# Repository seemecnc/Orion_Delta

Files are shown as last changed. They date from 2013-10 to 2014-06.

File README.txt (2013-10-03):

The ORION Delta 3D Printer by SeeMeCNC

Open-Source Files are published here on github, free to use/modify/share as you like.  We hope that some part of this design will inspire you to build and create new things!  If it does, please share your ideas/designs/concepts either through github here, or on 
http://forum.seemecnc.com  

Firmware used is a fork of repeater-firmware, and is kept in this github repo and maintained to be a direct drop-in for all pre-assembled ORION machines.  

The ORION Delta 3D Printer is a new delta-platform machine developed by SeeMeCNC.  Designed to be more compact than the Rostock MAX, more portable and more rigid. 

The ORION is a derivative stemming from our original Rostock MAX, which is a derivative of Johann's Rostock "original".  While there are many new delta designs, the ORION is built on solid, proven history, including many changes and design enhancements from both the community, as well as observations from running multiple delta machines for thousands of hours.  

All plastic parts are injection molded, with the exception of the EZ Fan shroud, which is printed on the machine as a first test-print, then attached to the next machine being assembled :)  All CNC machined parts are made from either Aluminum, Brass or PEEK (the hot end insulator).  Lasercut parts are produced from 1/4" Melamine laminated, which is comprised of an MDF core with high temp, high pressure melamine laminate on both surfaces.  This provides a light weight, yet rigid framework that is far more stable than a plywood material to moisture, pressure, temperature etc…

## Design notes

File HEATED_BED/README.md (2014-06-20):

ORION Heated Bed files

Designed by partdaddy

Released as open-source hardware with attribution

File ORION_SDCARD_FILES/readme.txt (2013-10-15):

The files on the SD card are included on the machine once shipped.

There is a folder for FIRMWARE which contains the actual firmware used on 
your machine.  

The folder labeled GCODE has sample gcode prints that were printed on your machine
to test it before shipping

The folder calibration contains GCODE files that can be used to calibrate
the three towers

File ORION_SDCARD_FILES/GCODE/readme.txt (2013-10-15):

fan.gco is the printable fan shroud for the 25mm fan on the platform.
It isn't necessary, but is a printable add-on, something fun to print
on your machine!

blinky.gco is the Blinky Eye token we print and send with your machine.  You can
download the original from http://repables.com

vase.gco is another sample print we use on your machine.  It is from thingiverse.com, 
and can be downloaded from the link http://www.thingiverse.com/thing:18672

ENJOY!

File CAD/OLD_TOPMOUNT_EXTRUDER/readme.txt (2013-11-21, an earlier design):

These are the CAD files for the original top mounted extruder setup like was shown on the 
prototype machine released at Detroit maker faire.  These files will only work with the first design top plate with the cutouts, or you 
could drill your own mounting holes

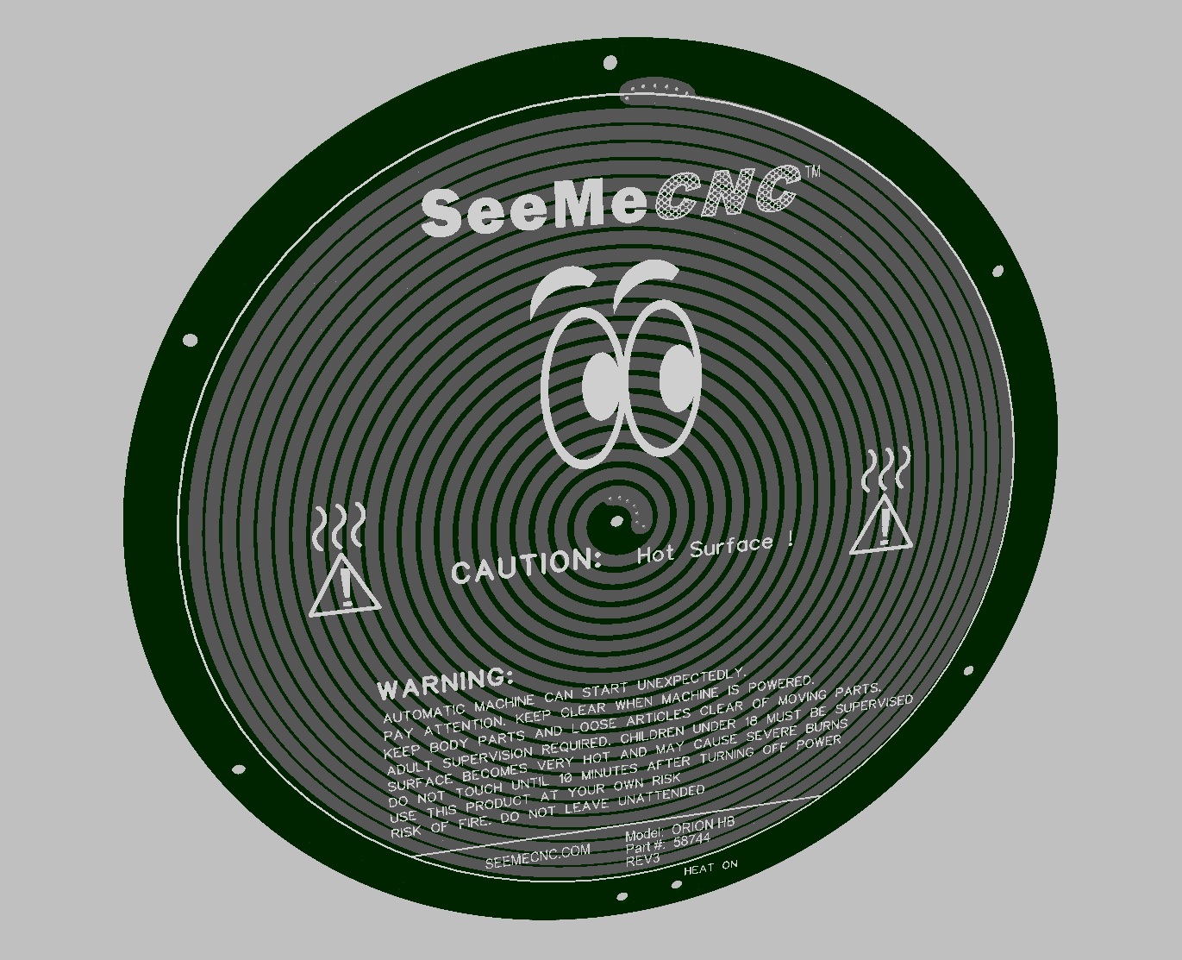
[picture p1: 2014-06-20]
HEATED_BED/58744 ORION HB REV3/58744 ORION HB REV3.jpg

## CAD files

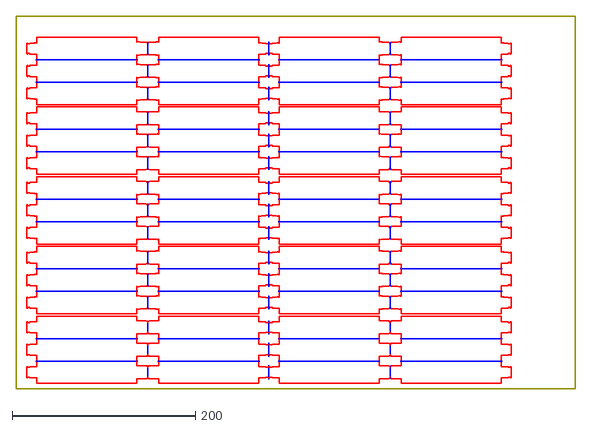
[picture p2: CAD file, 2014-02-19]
CAD/ACRYLIC_IDLER_COVERS.DXF
609.6 x 406.4

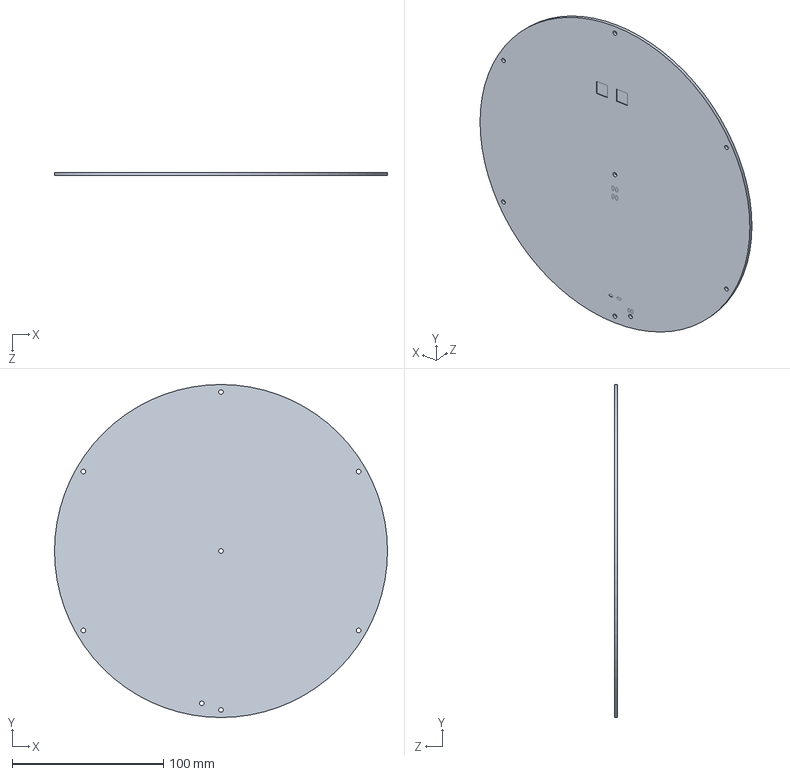
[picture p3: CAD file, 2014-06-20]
HEATED_BED/ORION HEATED BED.SLDPRT
220.0 x 220.0 x 2.20 mm

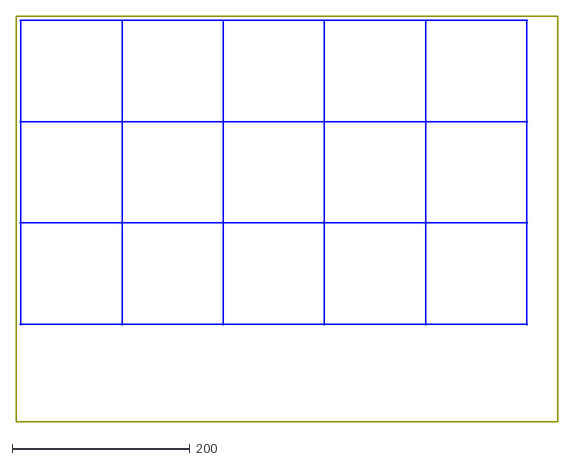
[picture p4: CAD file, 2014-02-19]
CAD/ACRYLIC_SQUARES_114MM.DXF
609.6 x 457.2

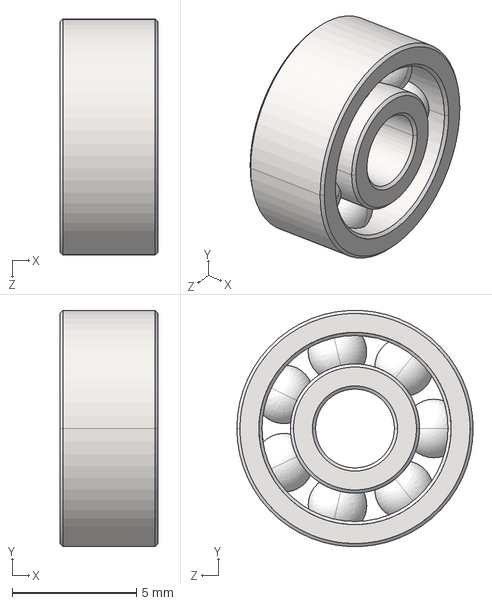
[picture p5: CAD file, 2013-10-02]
CAD/IGES/Ball Bearing 0125ID - 0375OD - 0156W.IGS
3.96 x 9.51 x 9.53 mm

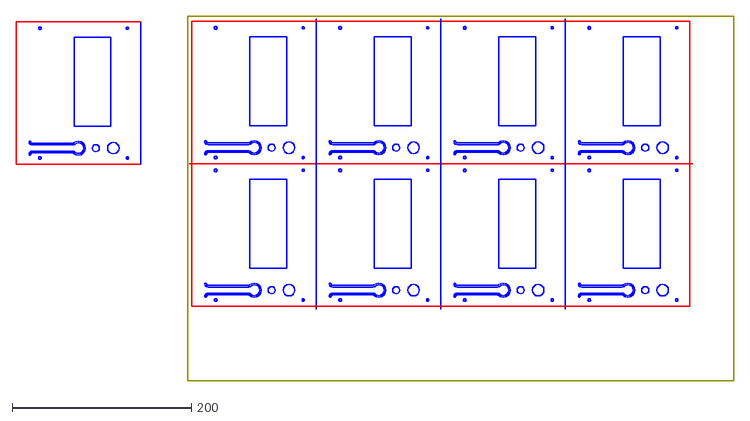
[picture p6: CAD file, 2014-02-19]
CAD/ACRYLIC_FACEPLATE_FLEXY_V3.DXF
801.1 x 406.4

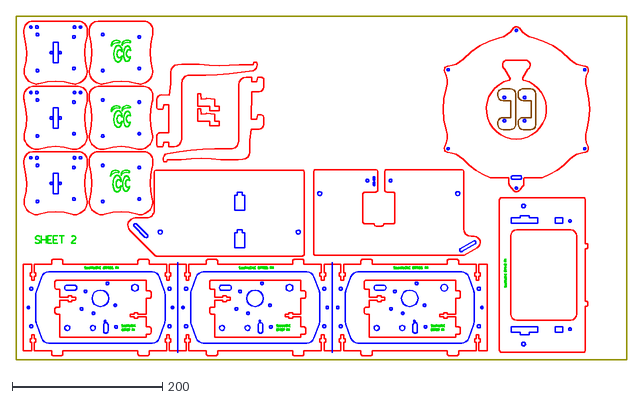
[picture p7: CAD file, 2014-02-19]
CAD/ORION_SHEET_2.DXF
812.8 x 457.2

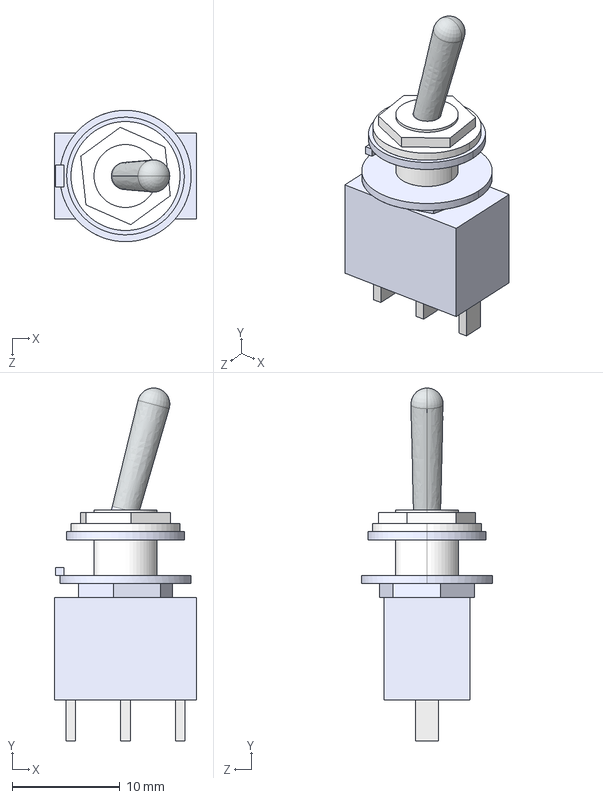
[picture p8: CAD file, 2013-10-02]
CAD/IGES/Switch - Single Pole Double Through - SPDT.IGS
13.2 x 32.8 x 12.2 mm

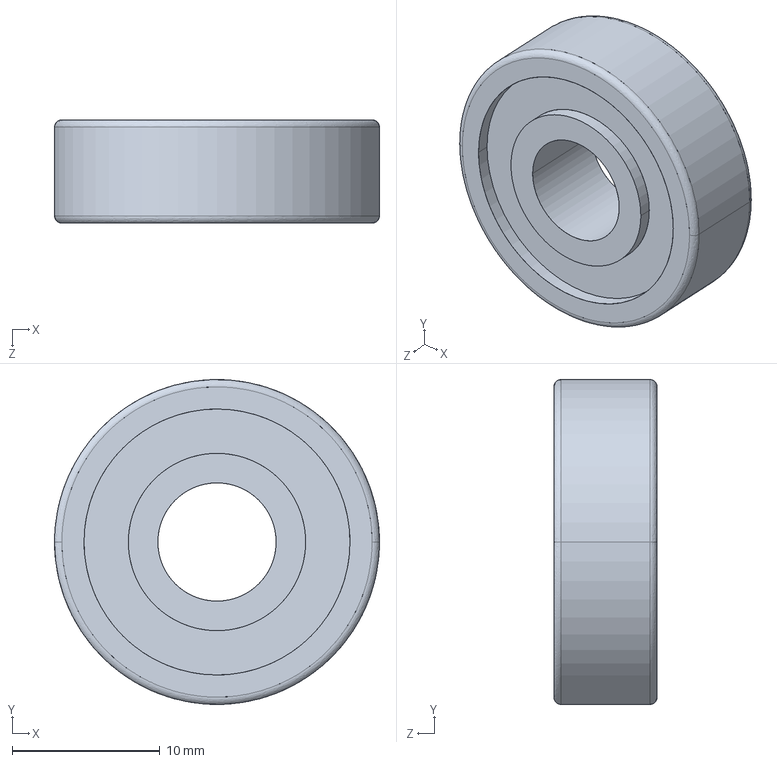
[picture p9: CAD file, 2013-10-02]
CAD/IGES/608-bearing.IGS
22.0 x 22.0 x 7.00 mm

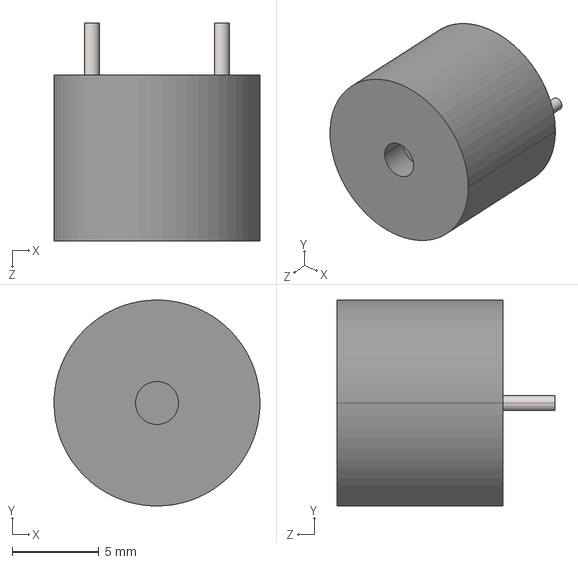
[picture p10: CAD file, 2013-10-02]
CAD/IGES/Piezo Beeper HSD.IGS
11.9 x 11.9 x 12.6 mm

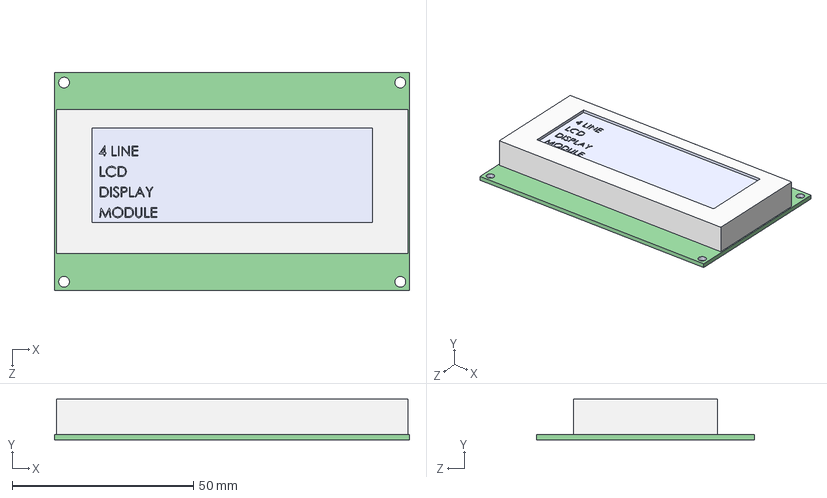
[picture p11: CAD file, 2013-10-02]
CAD/IGES/LCD4linedisplay.IGS
98.0 x 11.3 x 60.2 mm

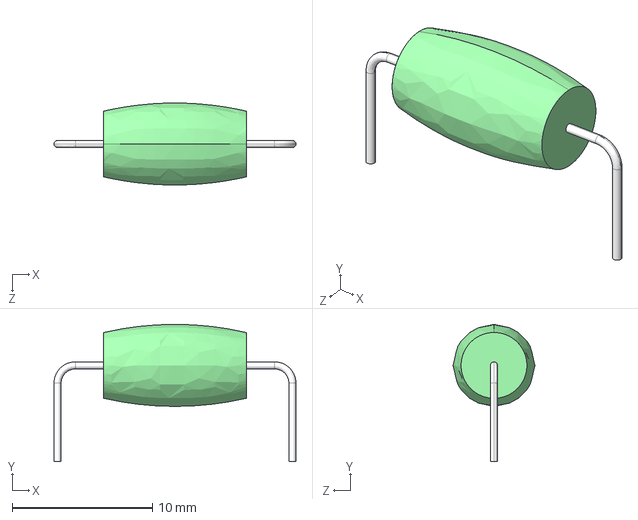
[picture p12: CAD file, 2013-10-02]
CAD/IGES/Resistor 6.8ohm Ceramic Wire Wound.IGS
17.2 x 9.77 x 5.84 mm

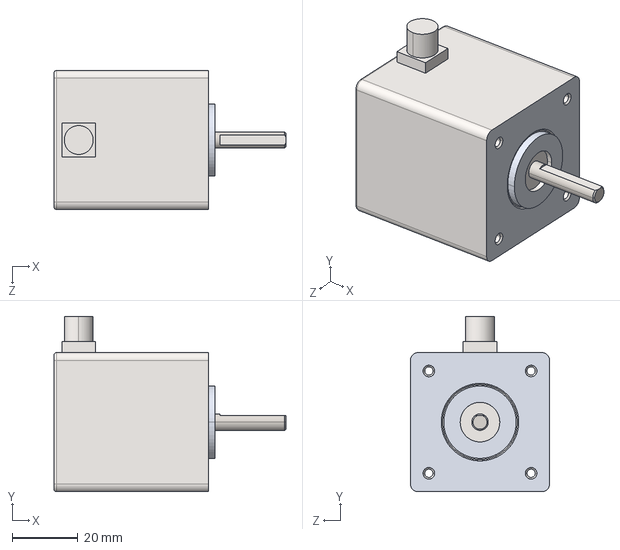
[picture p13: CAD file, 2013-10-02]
CAD/IGES/NEMA 17 Stepper.IGS
70.3 x 53.2 x 42.2 mm

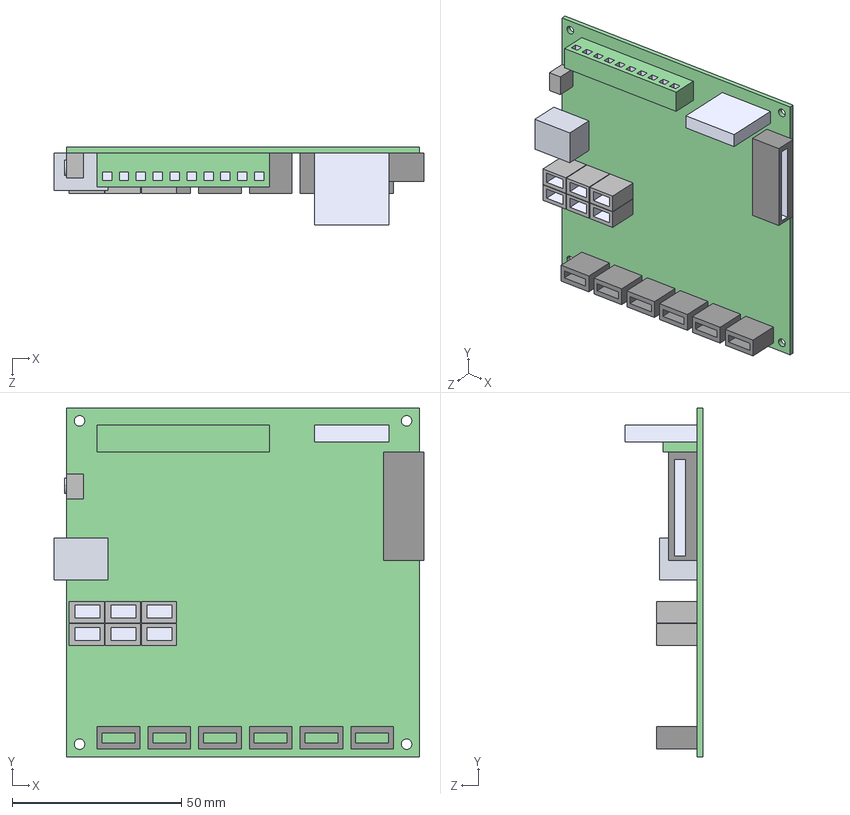
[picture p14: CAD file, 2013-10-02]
CAD/IGES/RAMBo Board Model Only.IGS
109.4 x 103.1 x 23.0 mm

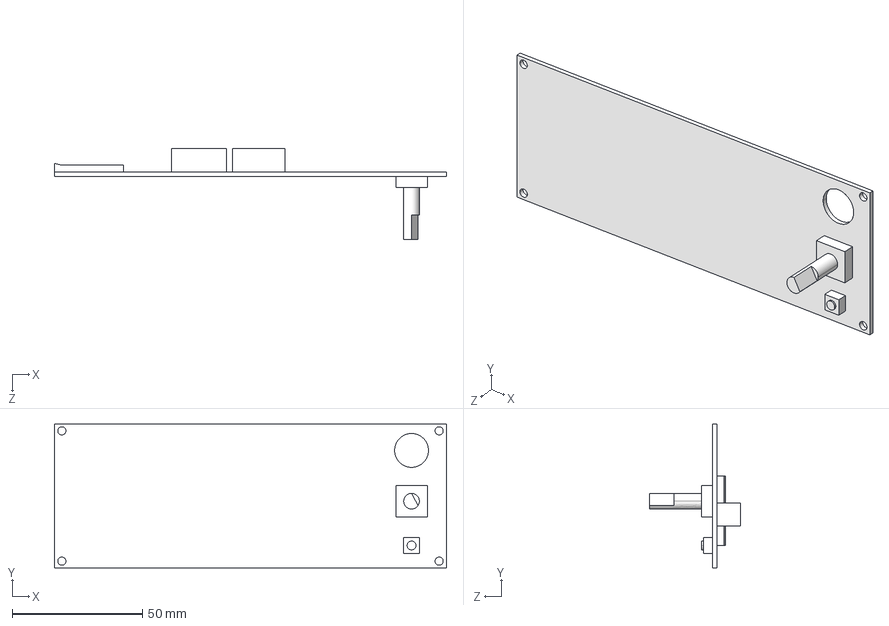
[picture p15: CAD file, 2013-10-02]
CAD/IGES/LCD.IGS
150.5 x 55.1 x 35.0 mm

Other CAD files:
CAD/IGES/Part1.sldprt
CAD/IGES/ORION HEATED BED.IGS
CAD/IGES/Switch Micro Lever.IGS
CAD/IGES/40mmFAN.IGS
CAD/IGES/17505 LEG.IGS
CAD/IGES/44010 FOOT.IGS
CAD/IGES/68304 platform.IGS
CAD/IGES/68309 Universal Joint.IGS
CAD/IGES/68315 Eccentric Spacer_machined.IGS
CAD/IGES/68316 Bowden Hot End PTC adapter.IGS
CAD/IGES/68324 Hot End Spacer.IGS
CAD/IGES/68325 U Shaft Axle.IGS
CAD/IGES/68332 U Mount Base.IGS
CAD/IGES/68334 hot end Standoff.IGS
CAD/IGES/68336 Bearing Sleeve.IGS
CAD/IGES/68340 Bushing Washer 3mm.IGS
CAD/IGES/68447 4mm ID x 6mm OD x 32.5mm Long PTFE Tube for 1750 Hot End.IGS
CAD/IGES/68447 Heater Head 1750mm.IGS
CAD/IGES/68448 Teflon Tube 2mm ID x 4mm OD for 1750mm filament.IGS
CAD/IGES/68449 Feed Tube Insulator 1750mm.IGS
CAD/IGES/68451 NO22LE 050mm.IGS
CAD/IGES/70766 EZFan Shroud.IGS
CAD/IGES/70769 Spacer.IGS
CAD/IGES/70781 Drive Base Plate.IGS
CAD/IGES/70782 Drive Roller.IGS
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

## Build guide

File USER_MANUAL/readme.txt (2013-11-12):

###   User Manual for the Orion Delta 3D printer ###

Changelog:

date	desc. of changes
11/12/2013 Started adding files

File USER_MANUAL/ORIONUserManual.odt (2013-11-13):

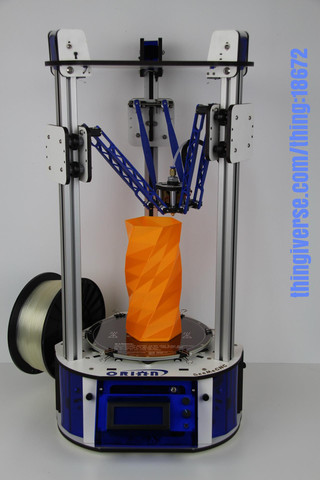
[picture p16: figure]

Orion Delta™ 3D Printer Manual

v1.00, November 13th, 2013

This guide will take you through the steps to set up and operate your new 3D printer from SeeMeCNC. You’ll find instructions on calibration, software, maintenance and more all in this manual. As a new SeeMeCNC™ owner, you’ll also find a ton of great resources on the forums at www (http://www.forum.seemecnc.com/). (http://www.forum.seemecnc.com/)forum (http://www.forum.seemecnc.com/). (http://www.forum.seemecnc.com/)seemecnc (http://www.forum.seemecnc.com/). (http://www.forum.seemecnc.com/)com (http://www.forum.seemecnc.com/)

###### Unboxing your new Orion Delta™ 3D Printer

With your box standing in the upright position, carefully cut the packing tape along the top edges and across the taped seam in the box.

After you’ve cut the tape, open the top of the box being careful of any packaging staples. You’ll find the machine tucked inside and wrapped in a protective expanding foam shell. Remove the machine and foam all as one by pulling straight up out of the box. Be careful not to drop the machine once it’s out of the box and the foam is still around it.

Carefully cut and remove the stretch wrap film that is holding the power/USB cables and accessories on the top plate, as well as the stretch wrap holding your filament to the table top and glass build surface. Place the power cable/USB cable and accessories to the side for now, and set the machine on a table or desk close to a grounded power outlet where you will use your new machine.

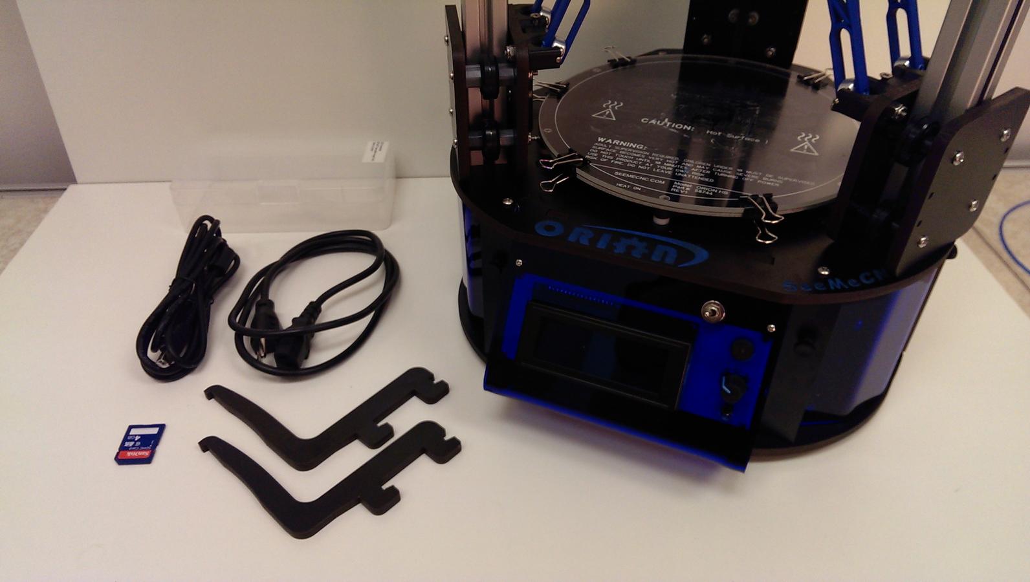
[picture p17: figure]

###### Installing the power cord and selecting input voltage

Locate the two black thumb screws on the left side panel and remove both screws and set them aside.

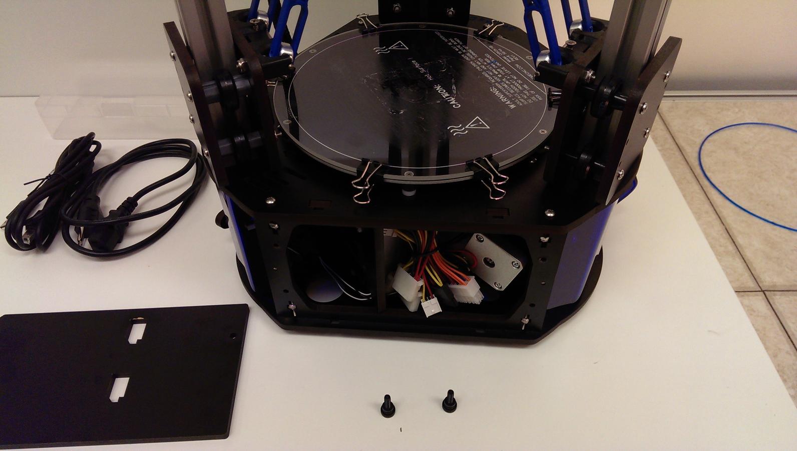
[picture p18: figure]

Using a small flat head screwdriver make sure the power supply input voltage switch is set to the correct voltage for your country. Pass the power cord for the power supply through the hole in the bottom of the Orion and plug it into the power supply.

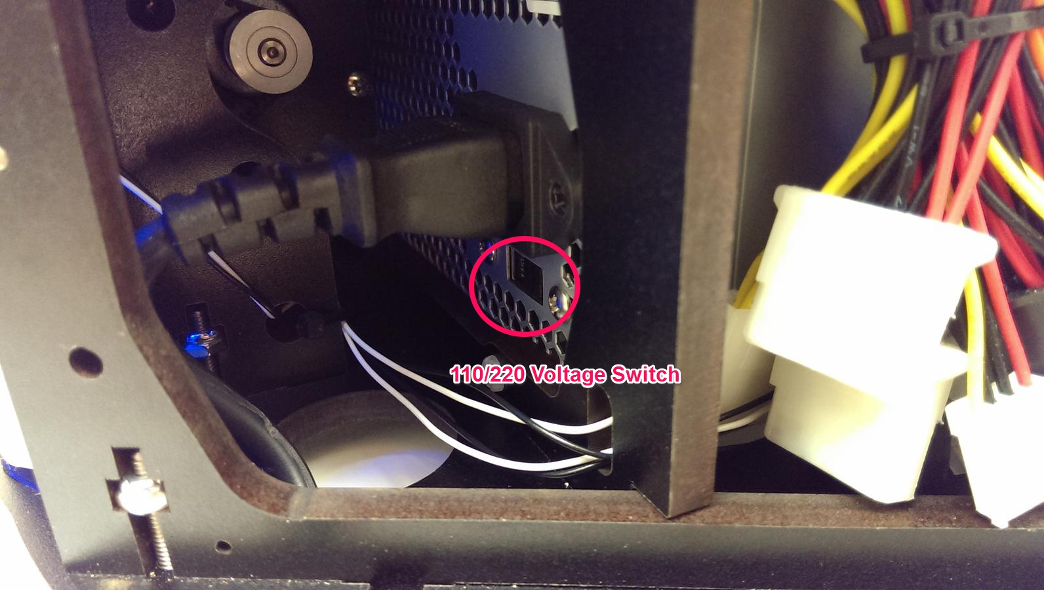
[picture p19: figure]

Place the left side cover back on the machine and screw the two thumb screws back in firmly, making sure that the filament routing tab is to the top and rear side of the machine.

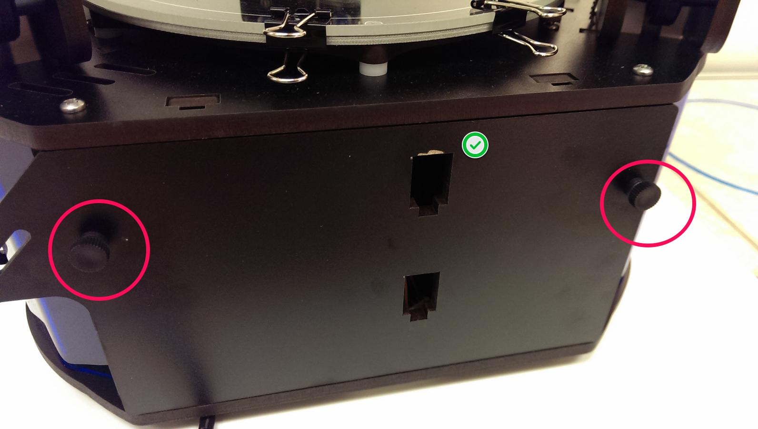
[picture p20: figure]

###### Installing the USB cable

The USB cable only needs to be used if you wish to manually control the machine from the software on your PC. you can print and do most calibration standalone, without the USB cable attached. We recommend hooking it up for starters, so if you need to connect it to your computer to make changes etc… the cable is already installed.

Facing the front of the machine, remove the two black thumb screws on each side of the control panel and set them aside. Carefully pull out on the top of the front panel until it is past the table of the machine, then lift up slightly and set it to the right making sure not to pull on any of the cables connected to the LCD screen.

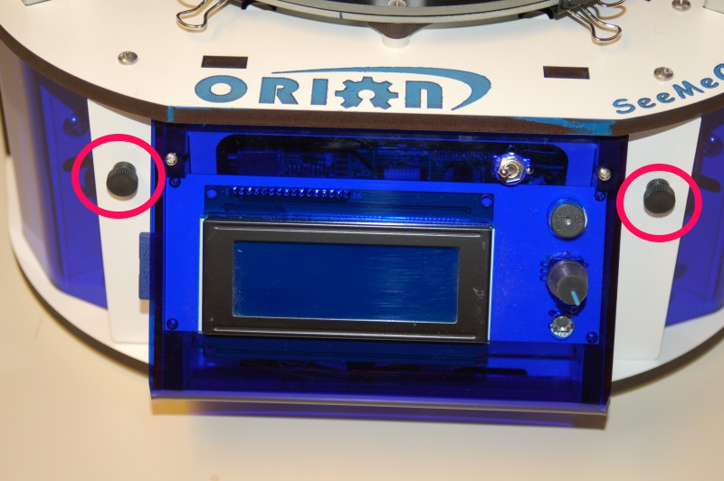
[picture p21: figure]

Now pass the end of the USB cable up through the hole in the bottom left of the base and plug it into the USB input on the electronics board. Next, replace the front panel by putting the bottom in first, then tilting the top in. Please be careful as it’s a tight fit. Re-install the two black thumb screws and tighten them finger tight.

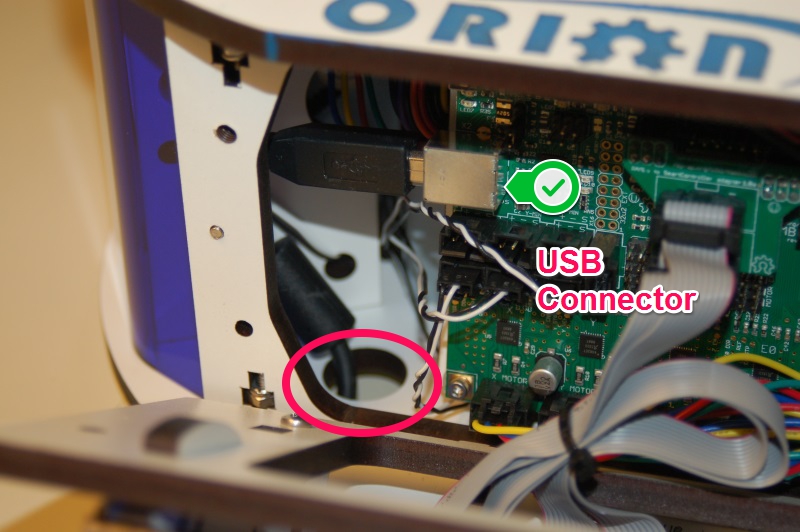
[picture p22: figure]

###### Getting ready to power up for the first time

The machine is shipped with the three arms in the inverted position to help protect the platform and hotend from damage during shipping. To put them into printing position, simply take one arm plate at a time and move it up to the top, then the next and so on.

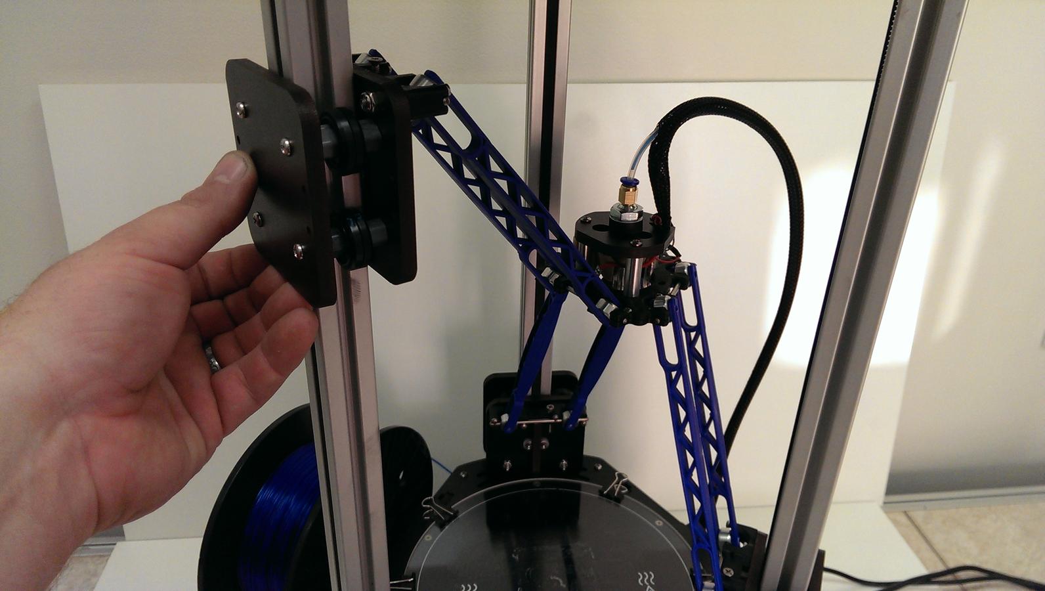
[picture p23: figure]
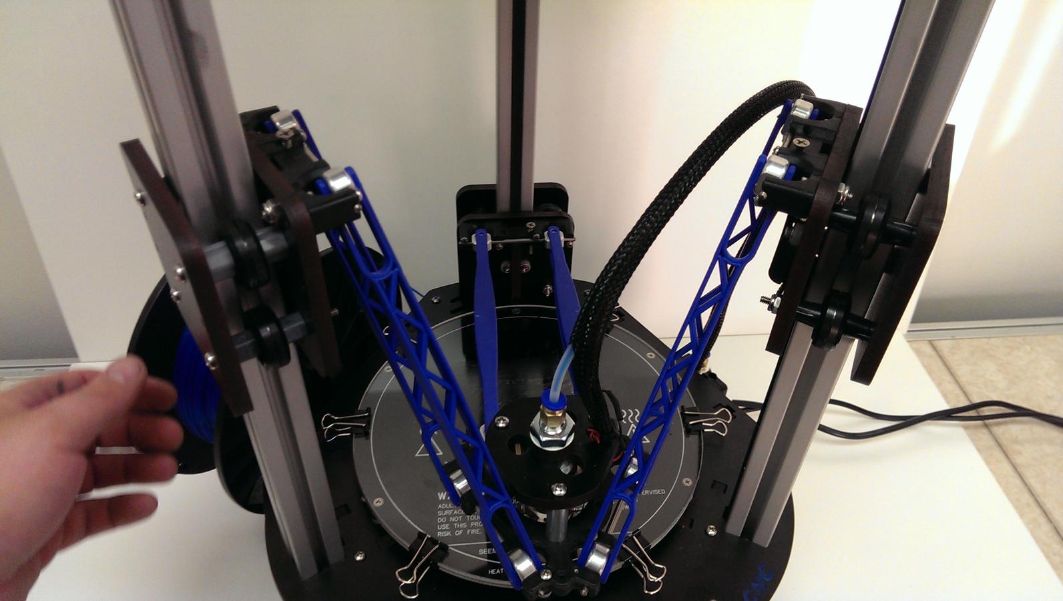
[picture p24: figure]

Once you have the arms in the correct position as the photo above shows and you are sure you have the power cord plugged into a grounded outlet, go ahead and turn the power on.

The LCD should light up and display the temperature for the hotend and bed as room temperature (approximately 20-25c).

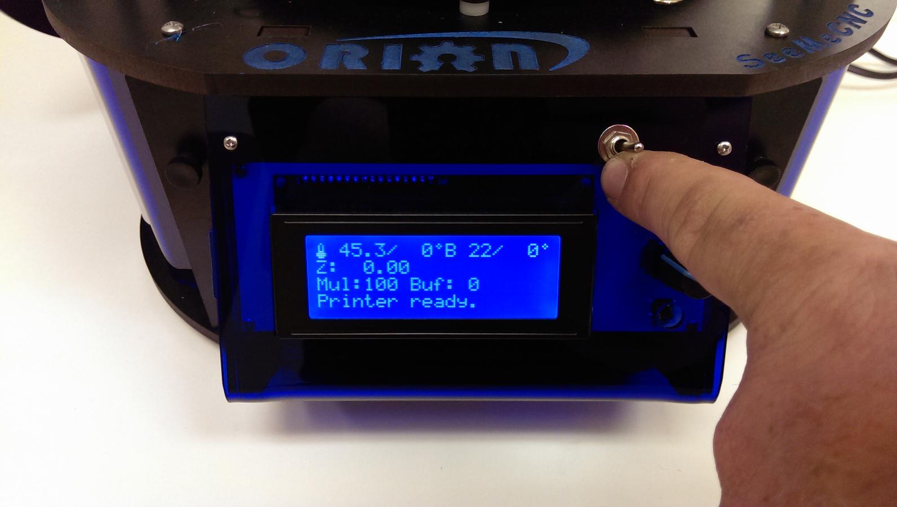
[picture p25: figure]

Now, using the knob selector on the control panel, press in on the knob once to access the main menu, and turn the knob to move the cursor to “QUICK SETTINGS” and press again, then select “HOME ALL” and press again. All three arms should move up to the limit switches then back off slightly and go up to the switch again, and this is called “Home Position”.

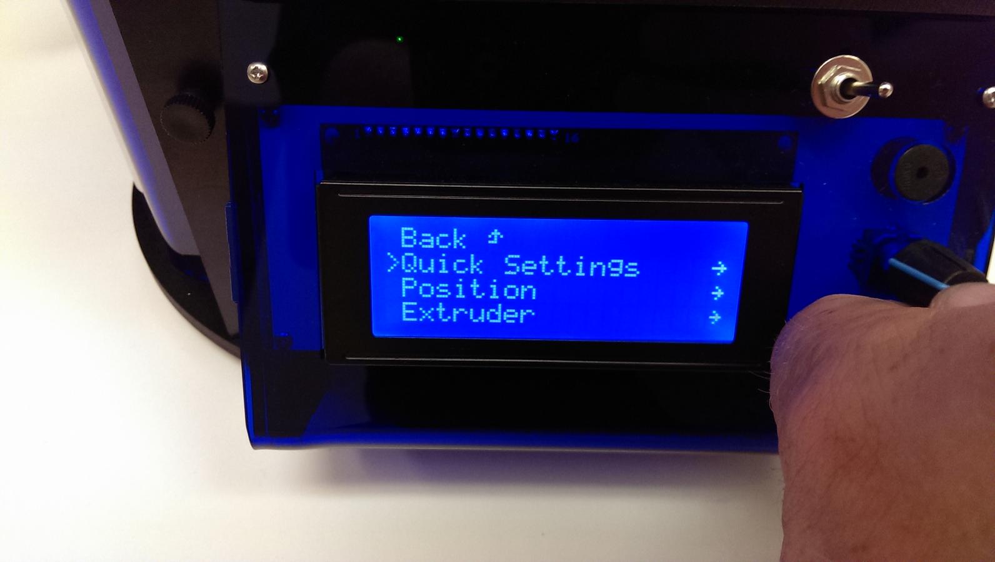
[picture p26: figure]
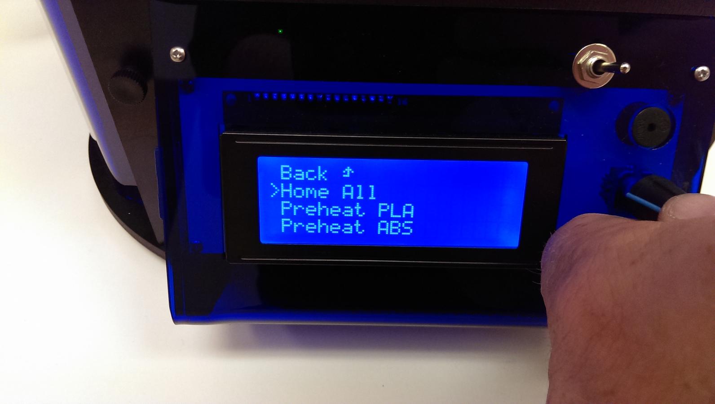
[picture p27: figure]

###### Setting the Z height

Congrats! Your new Orion Delta™ 3D printer is alive! But before we get to printing lets take a minute to set the Z height of the machine as it could have been bumped during shipping and it needs to be super accurate to get the best first-layer adhesion of your prints.

Using the control panel on the machine to set the Z height is really easy. You’ll find you may need to do this from time to time or after changing to a new build plate or nozzle etc…

To set the Z height you want to warm the bed and hotend to close to printing temperature to let any heat expansion take place. To do so, click on the knob and scroll to “QUICK SETTINGS” then “PREHEAT ABS” and click. This will set the heated bed to 90c and the hotend to 175c. This is less than the melt temp for ABS, but a good holding temperature that will make sure that any ABS filament doesn’t burn as it sits in the hotend waiting for the bed to heat up. It may take up to 15 minutes to heat the bed to 90c depending on the room temperature, but it’s important to let it heat up before setting the Z height.

Once the bed and hotend are up to temp, click on the knob and from the main menu scroll down to “CALIBRATION” then down to “DELTA CALIB” then down to “HOME ALL” and press to home the machine first. After the machine is homed, scroll to “Z POS FAST” and click. Now, make sure you turn the knob to the right to lower the head. If you accidentally raise the head into the limit switches, it will stop moving but keep updating the Z position on the display. If that happens, go back to “HOME ALL” and home again first, then move down. Using the “Z POS FAST” screen, jog the hotend down to about a half-inch or so above the table.

Make sure the nozzle is clean and there is no filament hanging from the nozzle (Be careful, it’s hot now!). Take a single sheet of notebook paper and place it under the nozzle.

Click back and choose “Z POS” which puts the jogging into fine mode, and jog down until the nozzle just begins to “snag” on the paper. Now click back and scroll up a few to “SET MEASURED POS” to store the new Z height to memory. That’s it! You’ve now set the Z height to the table and are ready to load up the filament and print!

###### Loading Filament and setting up the Spool Holder

The spool holders are capable of using spools with the standard size hole as well as spools with a smaller hole like Taulman™. For starting with the included spool of ABS you’ll want to use both spool holders by holding them together and inserting them in the cutouts in the left side panel. Notice how they slip in then down to ‘lock’ onto the side panel. If you were to use a smaller spool, you can use only one of these spool holders and you’ll see there is a tab in the center of the cutouts to hold a single spool holder for those spools.

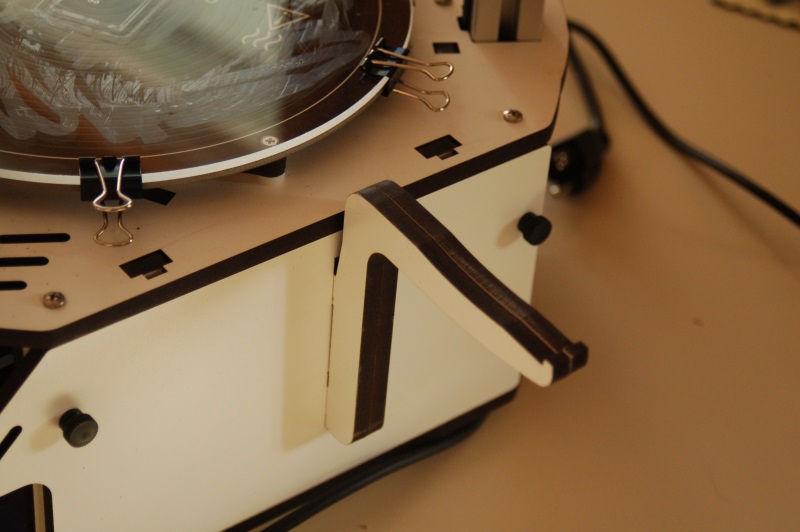
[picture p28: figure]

Now take the spool of ABS that came with your machine and open it up. Remove the loose end of the filament and trim the end so it’s a nice and clean end with no kinks. Put the spool on the holder so the filament un-spools OVER the top of the spool, and pass it through the filament guides per the picture below.

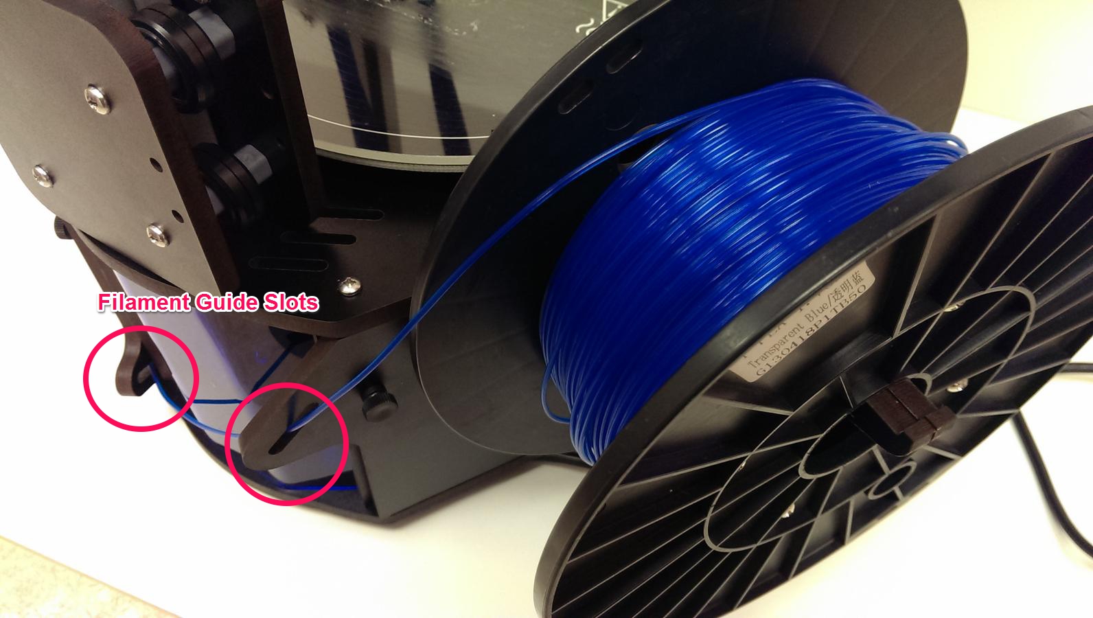
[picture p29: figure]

Now take the end of the filament, making sure it is straight and pass it up behind the red lever on the extruder. Squeeze the red lever to release the tensioner and push the filament up and into the extruder body. You should see it in the tube, keep pushing by hand until it is all the way to the hotend. You will feel it get harder to push once it’s inside the hotend itself.

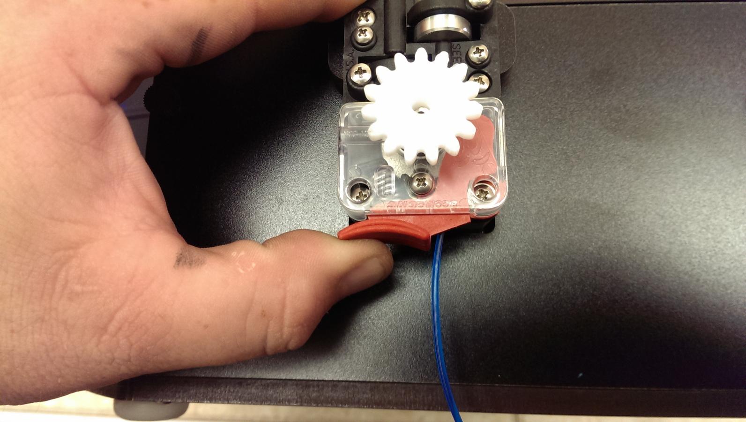
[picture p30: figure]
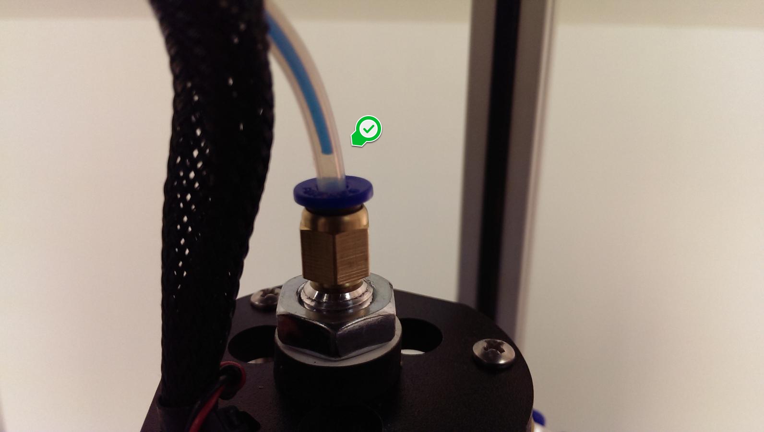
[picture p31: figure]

Now on the LCD screen, click and go to “QUICK SETTINGS” and scroll down to “DISABLE STEPPERS” and click. This will unlock the motors allowing you to turn the extruder by hand to purge the hotend. Now go to the main menu and click on “EXTRUDER” then scroll down to “EXTRUDER” and click, then set the temp to 215 and click to set the new temp. You can wait for the screen to go back automagically to the main screen or scroll up and click “BACK” and get to the home screen.

Once the hotend is up to temperature, reach around the right side and rotate the knob on the extruder counter clockwise to feed filament slowly into the hotend and you will see it start to flow out the nozzle. Let it flow out about 4” or so, then stop and remove the hanging filament.

###### Changing Filament

Changing the filament on your Orion is a very simple process.

First, you'll want to bring the hotend up to the temperature you normally set it at when you're printing.

Once the hotend is at operating temperature, pop the bowden tube off the hot end as shown in the following steps.

1. Grip the bowden tube with one hand and press down the blue ring and pull up on the bowden tube. You may need to depress the red release lever on the extruder in order to get enough slack to pull the bowden tube free of the hotend fitting.

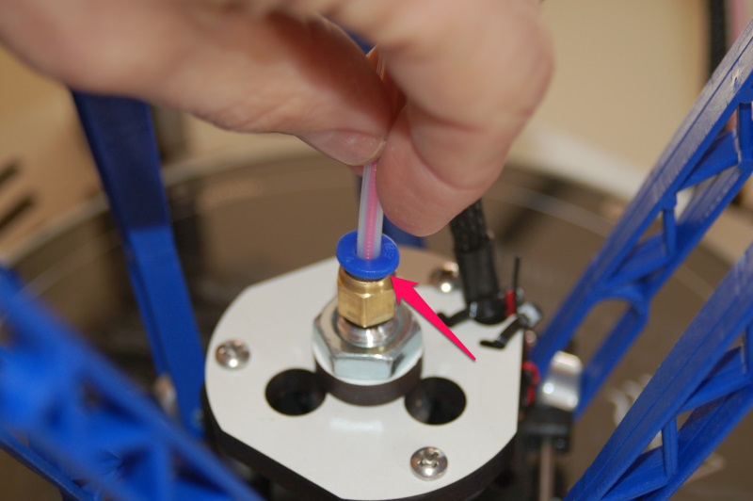
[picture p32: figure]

When the filament pulls free, it should look something like the photo below.

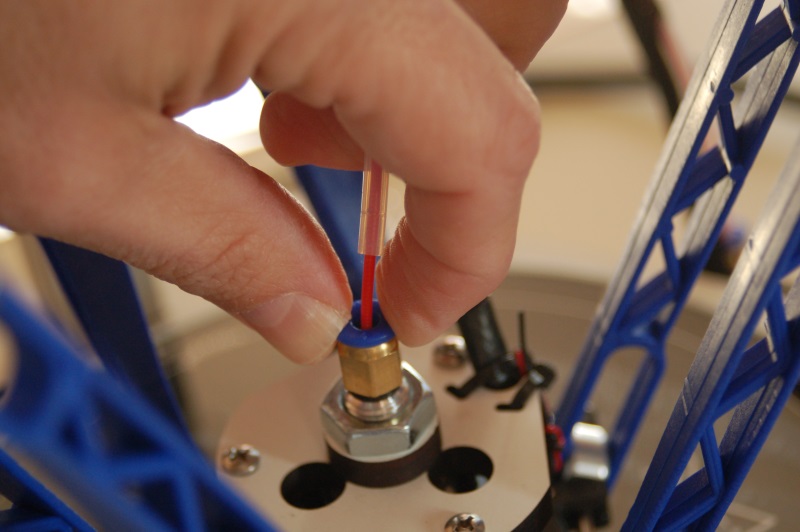
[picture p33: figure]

2. Cut off the filament flush with the end of the bowden tube.

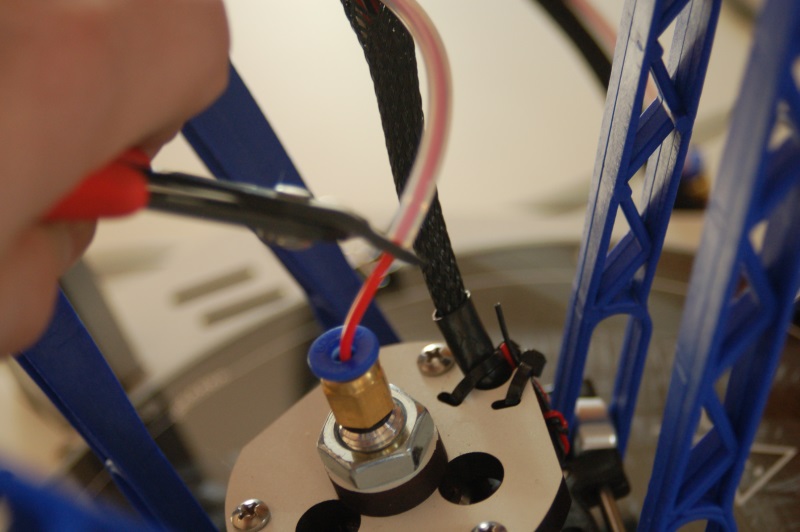
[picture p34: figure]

3. Pull the filament stub from the hotend and then re-insert the bowden tube into the hotend, making sure it seats fully.

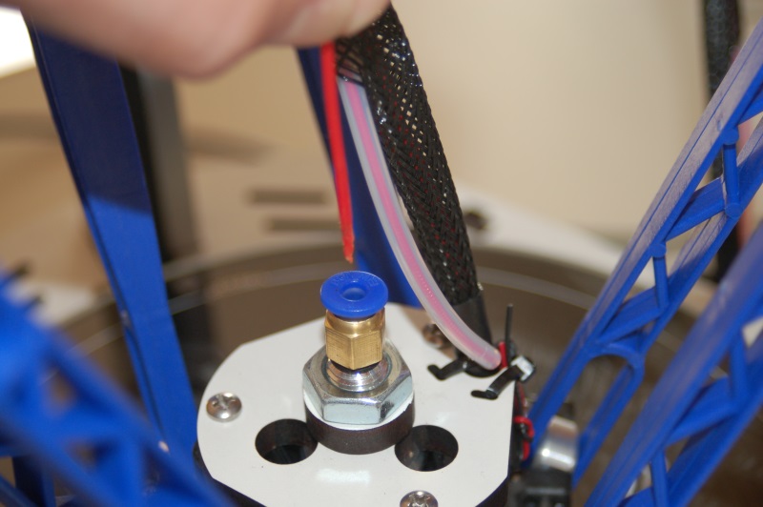
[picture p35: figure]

###### SD Card

The SD card included with your new Orion Delta™ 3D Printer has folders already on it with some sample prints as well as the firmware that was used to calibrate your machine.

The SD card goes in the left side of the control panel, label facing inwards, through a slot in the blue acrylic side panel as shown below.

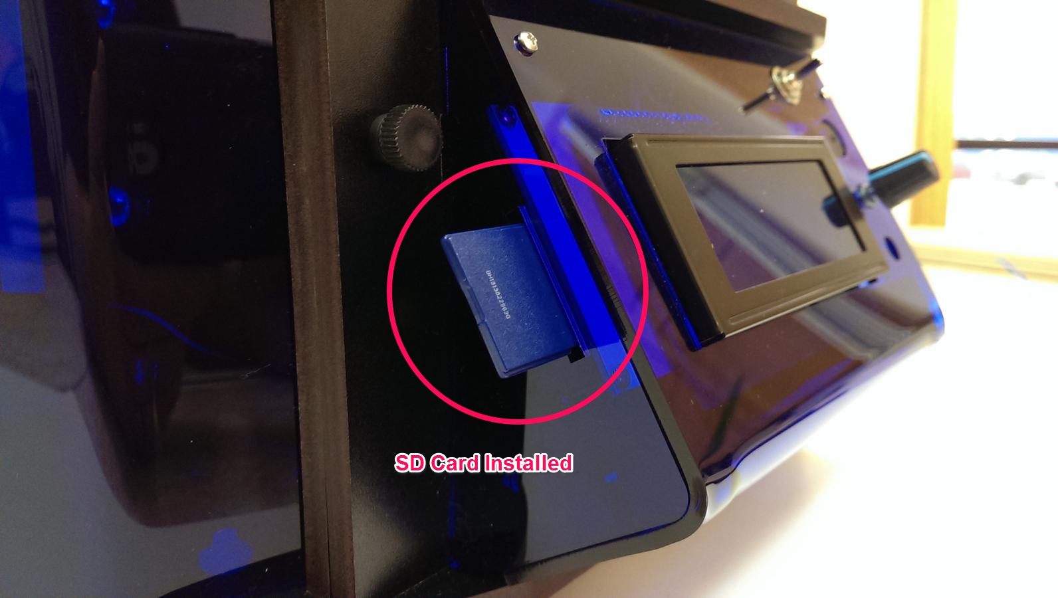
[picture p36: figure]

You can save your G Code print files on the card to print directly from it. To do so, with the SD card inserted, click to the main menu and scroll down to “SD CARD” then “PRINT FILE” then select the file you want to print and click to start that print. You can also pause, resume and delete files from the LCD control panel. To cancel a print job when running from the SD card, choose “SD CARD” then “PAUSE PRINT” then go back to “QUICK SETTINGS” and “HOME ALL”

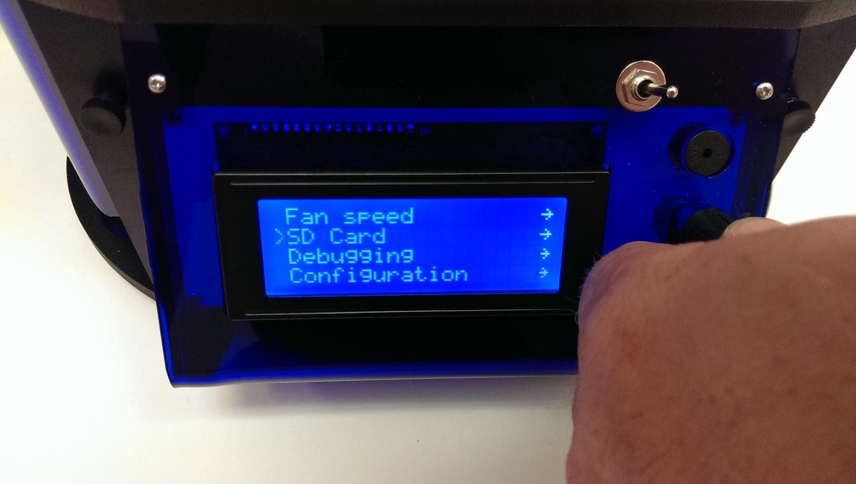
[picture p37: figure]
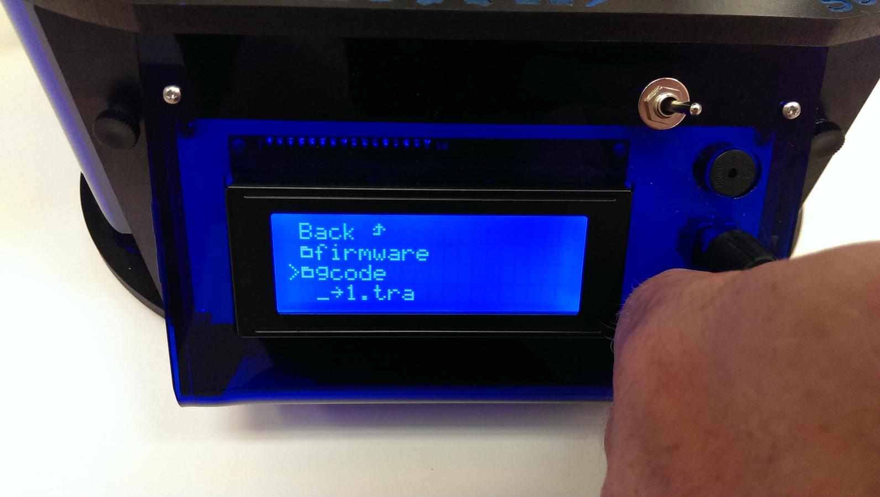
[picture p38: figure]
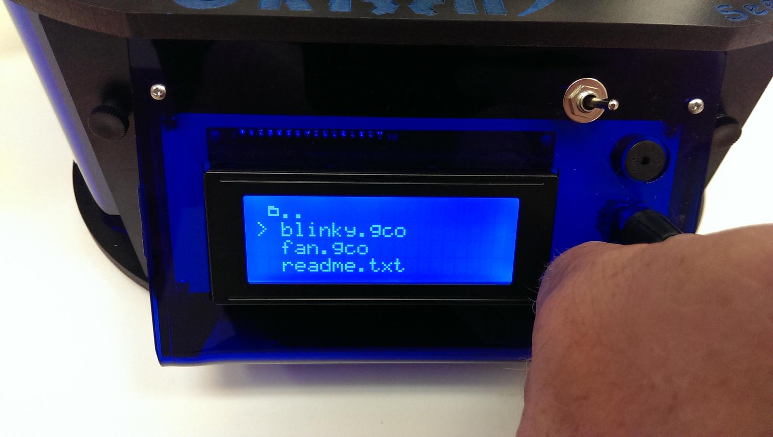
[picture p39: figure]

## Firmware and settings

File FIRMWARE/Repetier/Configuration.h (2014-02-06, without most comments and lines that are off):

#define CONFIGURATION_H
#define BEEPER_PIN 79
#define NUM_EXTRUDER 1
#define MOTHERBOARD 301
#include "pins.h"
#define DRIVE_SYSTEM 3
#if DRIVE_SYSTEM==3
    #define DELTA_DRIVE_TYPE 0
    #if DELTA_DRIVE_TYPE == 0
      #define BELT_PITCH 2
      #define PULLEY_TEETH 20
      #define PULLEY_CIRCUMFERENCE (BELT_PITCH * PULLEY_TEETH)
    #elif DELTA_DRIVE_TYPE == 1
      #define PULLEY_DIAMETER 10
      #define PULLEY_CIRCUMFERENCE (PULLEY_DIAMETER * 3.1415927)
    #endif
    #define STEPS_PER_ROTATION 200
    #define MICRO_STEPS 16
    #define MAX_DELTA_SEGMENTS_PER_LINE 30
    #define AXIS_STEPS_PER_MM ((float)(MICRO_STEPS * STEPS_PER_ROTATION) / PULLEY_CIRCUMFERENCE)
    #define XAXIS_STEPS_PER_MM AXIS_STEPS_PER_MM
    #define YAXIS_STEPS_PER_MM AXIS_STEPS_PER_MM
    #define ZAXIS_STEPS_PER_MM AXIS_STEPS_PER_MM
#else
    #define XAXIS_STEPS_PER_MM 80.000
    #define YAXIS_STEPS_PER_MM 80.000
    #define ZAXIS_STEPS_PER_MM 80.000
#endif
#define EXTRUDER_FAN_COOL_TEMP 40
#define EXT0_X_OFFSET 0
#define EXT0_Y_OFFSET 0
#define EXT0_STEPS_PER_MM 92.4 //steves extruder    set to 92 for ezstruder
#define EXT0_TEMPSENSOR_TYPE 97
#define EXT0_TEMPSENSOR_PIN TEMP_0_PIN
#define EXT0_HEATER_PIN HEATER_0_PIN
#define EXT0_STEP_PIN E0_STEP_PIN
#define EXT0_DIR_PIN E0_DIR_PIN
#define EXT0_INVERSE true
#define EXT0_ENABLE_PIN E0_ENABLE_PIN
#define EXT0_ENABLE_ON false
#define EXT0_MAX_FEEDRATE 80
#define EXT0_MAX_START_FEEDRATE 40
#define EXT0_MAX_ACCELERATION 6500
#define EXT0_HEAT_MANAGER 1
#define EXT0_WATCHPERIOD 3
#define EXT0_PID_INTEGRAL_DRIVE_MAX 205
#define EXT0_PID_INTEGRAL_DRIVE_MIN 60
#define EXT0_PID_P   15.91
#define EXT0_PID_I   0.75
#define EXT0_PID_D 84.02
#define EXT0_PID_MAX 255
#define EXT0_ADVANCE_K 0.0f
#define EXT0_ADVANCE_L 0.0f
#define EXT0_WAIT_RETRACT_TEMP 		150
#define EXT0_WAIT_RETRACT_UNITS 	0
#define EXT0_SELECT_COMMANDS "M120 S5 P5\nM117 Extruder 1"
#define EXT0_DESELECT_COMMANDS ""
#define EXT0_EXTRUDER_COOLER_PIN -1  // turned off pin 7 to eliminate PWM issues with atmega chip
#define EXT0_EXTRUDER_COOLER_SPEED 255
#define EXT1_X_OFFSET 10
#define EXT1_Y_OFFSET 0
#define EXT1_STEPS_PER_MM 373
#define EXT1_TEMPSENSOR_TYPE 3
#define EXT1_TEMPSENSOR_PIN TEMP_2_PIN
#define EXT1_HEATER_PIN HEATER_2_PIN
#define EXT1_STEP_PIN E1_STEP_PIN
#define EXT1_DIR_PIN E1_DIR_PIN
#define EXT1_INVERSE false
#define EXT1_ENABLE_PIN E1_ENABLE_PIN
#define EXT1_ENABLE_ON false
#define EXT1_MAX_FEEDRATE 25
#define EXT1_MAX_START_FEEDRATE 12
#define EXT1_MAX_ACCELERATION 10000
#define EXT1_HEAT_MANAGER 1
#define EXT1_WATCHPERIOD 1
#define EXT1_PID_INTEGRAL_DRIVE_MAX 130
#define EXT1_PID_INTEGRAL_DRIVE_MIN 60
#define EXT1_PID_P   24
#define EXT1_PID_I   0.88
#define EXT1_PID_D 200
#define EXT1_PID_MAX 255
#define EXT1_ADVANCE_K 0.0f
#define EXT1_ADVANCE_L 0.0f
#define EXT1_WAIT_RETRACT_TEMP 	150
#define EXT1_WAIT_RETRACT_UNITS	40
#define EXT1_SELECT_COMMANDS "M120 S5 P15\nM117 Extruder 2"
#define EXT1_DESELECT_COMMANDS ""
#define EXT1_EXTRUDER_COOLER_PIN -1
#define EXT1_EXTRUDER_COOLER_SPEED 255
#define RETRACT_DURING_HEATUP true
#define PID_CONTROL_RANGE 15
#define SKIP_M109_IF_WITHIN 2
#define SCALE_PID_TO_MAX 0
#define NUM_TEMPS_USERTHERMISTOR0 28
#define USER_THERMISTORTABLE0  {\
  {1*4,864*8},{21*4,300*8},{25*4,290*8},{29*4,280*8},{33*4,270*8},{39*4,260*8},{46*4,250*8},{54*4,240*8},{64*4,230*8},{75*4,220*8},\
  {90*4,210*8},{107*4,200*8},{128*4,190*8},{154*4,180*8},{184*4,170*8},{221*4,160*8},{265*4,150*8},{316*4,140*8},{375*4,130*8},\
  {441*4,120*8},{513*4,110*8},{588*4,100*8},{734*4,80*8},{856*4,60*8},{938*4,40*8},{986*4,20*8},{1008*4,0*8},{1018*4,-20*8}	}
#define NUM_TEMPS_USERTHERMISTOR1 0
#define USER_THERMISTORTABLE1  {}
#define NUM_TEMPS_USERTHERMISTOR2 0
#define USER_THERMISTORTABLE2  {}
#define USE_GENERIC_THERMISTORTABLE_1
#define GENERIC_THERM1_R0 100000
#define GENERIC_THERM1_T0 25
#define GENERIC_THERM1_BETA 4450
#define GENERIC_THERM1_MIN_TEMP -20
#define GENERIC_THERM1_MAX_TEMP 300
#define GENERIC_THERM1_R1 0
#define GENERIC_THERM1_R2 4700
#define USE_GENERIC_THERMISTORTABLE_2
#define GENERIC_THERM2_R0 100000
#define GENERIC_THERM2_T0 25
#define GENERIC_THERM2_BETA 4367
#define GENERIC_THERM2_MIN_TEMP -20
#define GENERIC_THERM2_MAX_TEMP 300
#define GENERIC_THERM2_R1 0
#define GENERIC_THERM2_R2 4700
#define GENERIC_THERM3_R0 1042.7
#define GENERIC_THERM3_T0 170
#define GENERIC_THERM3_BETA 4036
#define GENERIC_THERM3_MIN_TEMP -20
#define GENERIC_THERM3_MAX_TEMP 300
#define GENERIC_THERM3_R1 0
#define GENERIC_THERM3_R2 4700
#define GENERIC_THERM_VREF 5
#define GENERIC_THERM_NUM_ENTRIES 28
#define HAVE_HEATED_BED true   //for now, no heated bed
#define HEATED_BED_MAX_TEMP 115
#define SKIP_M190_IF_WITHIN 5
#define HEATED_BED_SENSOR_TYPE 98
#define HEATED_BED_SENSOR_PIN TEMP_BED_PIN  //CHANGE FROM TEMP_1_PIN TO TEMP_BED_PIN FOR RAMBo
#define HEATED_BED_HEATER_PIN HEATER_BED_PIN   //CHANGE FROM HEATER_1_PIN TO TEMP_BED_PIN FOR RAMBo
#define HEATED_BED_SET_INTERVAL 5000
#define HEATED_BED_HEAT_MANAGER 1
#define HEATED_BED_PID_INTEGRAL_DRIVE_MAX 255
#define HEATED_BED_PID_INTEGRAL_DRIVE_MIN 80
#define HEATED_BED_PID_PGAIN   15.0
#define HEATED_BED_PID_IGAIN   0.9
#define HEATED_BED_PID_DGAIN 40.0
#define HEATED_BED_PID_MAX 255
#define TEMP_PID true
#define MINTEMP 5
#define MAXTEMP 250
#define MIN_DEFECT_TEMPERATURE -10
#define MAX_DEFECT_TEMPERATURE 300
#define ANALOG_REF ANALOG_REF_AVCC
#define ENDSTOP_PULLUP_X_MIN true
#define ENDSTOP_PULLUP_Y_MIN true
#define ENDSTOP_PULLUP_Z_MIN true
#define ENDSTOP_PULLUP_X_MAX true
#define ENDSTOP_PULLUP_Y_MAX true
#define ENDSTOP_PULLUP_Z_MAX true
#define ENDSTOP_X_MIN_INVERTING true
#define ENDSTOP_Y_MIN_INVERTING true
#define ENDSTOP_Z_MIN_INVERTING true
#define ENDSTOP_X_MAX_INVERTING false
#define ENDSTOP_Y_MAX_INVERTING false
#define ENDSTOP_Z_MAX_INVERTING false
#define MIN_HARDWARE_ENDSTOP_X false
#define MIN_HARDWARE_ENDSTOP_Y false
#define MIN_HARDWARE_ENDSTOP_Z false
#define MAX_HARDWARE_ENDSTOP_X true
#define MAX_HARDWARE_ENDSTOP_Y true
#define MAX_HARDWARE_ENDSTOP_Z true
#define X_ENABLE_ON 0
#define Y_ENABLE_ON 0
#define Z_ENABLE_ON 0
#define DISABLE_X false
#define DISABLE_Y false
#define DISABLE_Z false
#define DISABLE_E false
#define INVERT_X_DIR true
#define INVERT_Y_DIR false
#define INVERT_Z_DIR true
#define X_HOME_DIR 1
#define Y_HOME_DIR 1
#define Z_HOME_DIR 1
#define max_software_endstop_r true
#define min_software_endstop_x false
#define min_software_endstop_y false
#define min_software_endstop_z false
#define max_software_endstop_x true
#define max_software_endstop_y true
#define max_software_endstop_z true
#define ENDSTOP_X_BACK_MOVE 10
#define ENDSTOP_Y_BACK_MOVE 10
#define ENDSTOP_Z_BACK_MOVE 10
#define ENDSTOP_X_RETEST_REDUCTION_FACTOR 4
#define ENDSTOP_Y_RETEST_REDUCTION_FACTOR 4
#define ENDSTOP_Z_RETEST_REDUCTION_FACTOR 4
#define ENDSTOP_X_BACK_ON_HOME 5
#define ENDSTOP_Y_BACK_ON_HOME 5
#define ENDSTOP_Z_BACK_ON_HOME 5
#define ALWAYS_CHECK_ENDSTOPS true
#define X_MAX_LENGTH 250
#define Y_MAX_LENGTH 250
#define Z_MAX_LENGTH 250
#define X_MIN_POS 0
#define Y_MIN_POS 0
#define Z_MIN_POS 0
#define MICROSTEP_MODES {16,16,16,16,16} // [1,2,4,8,16]
#define MOTOR_CURRENT {175,175,175,200,0} // Values 0-255 (RAMBO 135 = ~0.75A, 185 = ~1A)
#if DRIVE_SYSTEM==3
#define DELTA_DIAGONAL_ROD 178.0 // mm
#define DELTA_SEGMENTS_PER_SECOND_PRINT 200 // Move accurate setting for print moves
#define DELTA_SEGMENTS_PER_SECOND_MOVE 70 // Less accurate setting for other moves
#define END_EFFECTOR_HORIZONTAL_OFFSET 33.0
#define CARRIAGE_HORIZONTAL_OFFSET 38.4
#define PRINTER_RADIUS 145.7
#define DELTA_RADIUS (PRINTER_RADIUS-END_EFFECTOR_HORIZONTAL_OFFSET-CARRIAGE_HORIZONTAL_OFFSET)
#define STEP_COUNTER
#define SOFTWARE_LEVELING
#endif
#define STEPPER_INACTIVE_TIME 60000
#define MAX_INACTIVE_TIME 90000
#define MAX_FEEDRATE_X 150
#define MAX_FEEDRATE_Y 150
#define MAX_FEEDRATE_Z 150
#define HOMING_FEEDRATE_X 80
#define HOMING_FEEDRATE_Y 80
#define HOMING_FEEDRATE_Z 80
#define ENABLE_BACKLASH_COMPENSATION false
#define Z_BACKLASH 0
#define X_BACKLASH 0
#define Y_BACKLASH 0
#define RAMP_ACCELERATION 1
#define STEPPER_HIGH_DELAY 0
#define STEP_DOUBLER_FREQUENCY 12000
#define ALLOW_QUADSTEPPING true
#define DOUBLE_STEP_DELAY 1 // time in us
#define MAX_HALFSTEP_INTERVAL 1999
#define MAX_ACCELERATION_UNITS_PER_SQ_SECOND_X 4250
#define MAX_ACCELERATION_UNITS_PER_SQ_SECOND_Y 4250
#define MAX_ACCELERATION_UNITS_PER_SQ_SECOND_Z 4250
#define MAX_TRAVEL_ACCELERATION_UNITS_PER_SQ_SECOND_X 3000
#define MAX_TRAVEL_ACCELERATION_UNITS_PER_SQ_SECOND_Y 3000
#define MAX_TRAVEL_ACCELERATION_UNITS_PER_SQ_SECOND_Z 3000
#define MAX_JERK 17.5
#define MAX_ZJERK 17.5
#define MOVE_CACHE_SIZE 16
#define MOVE_CACHE_LOW 10
#define LOW_TICKS_PER_MOVE 250000
#define TIMER0_PRESCALE 64
#define MIN_EXTRUDER_TEMP 0
#define USE_OPS 1
#define OPS_MODE 0
#define OPS_MIN_DISTANCE 0.8
#define OPS_MOVE_AFTER 50.0
#define OPS_RETRACT_DISTANCE 1.5
#define OPS_RETRACT_BACKLASH 0.0
#define USE_ADVANCE
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

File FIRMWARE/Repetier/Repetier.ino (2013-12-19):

/*



THIS FIRMWARE IS FOR THE ORION DELTA


### Changelog: ###
added 
// adding heated bed kill to the kill button function
#if HEATER_BED_PIN>-1
    WRITE(HEATER_BED_PIN,0);
#endif 
to ui.cpp line ~2161 to disable heated bed when kill button is pressed


added kill button code to ui.cpp to home machine, kill heaters and not hang


    This file is part of Repetier-Firmware.

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
    This firmware is a nearly complete rewrite of the sprinter firmware
    by kliment (https://github.com/kliment/Sprinter)
    which based on Tonokip RepRap firmware rewrite based off of Hydra-mmm firmware.

    Main author: repetier

*/
/**
\mainpage Repetier-Firmware for Arduino based RepRaps
<CENTER>Copyright &copy; 2011-2013 by repetier
</CENTER>

\section Intro Introduction


\section GCodes Implemented GCodes

 look here for descriptions of gcodes: http://linuxcnc.org/handbook/gcode/g-code.html
 and http://objects.reprap.org/wiki/Mendel_User_Manual:_RepRapGCodes

Implemented Codes

- G0  -> G1
- G1  - Coordinated Movement X Y Z E
- G4  - Dwell S<seconds> or P<milliseconds>
- G20 - Units for G0/G1 are inches.
- G21 - Units for G0/G1 are mm.
- G28 - Home all axis or named axis.
- G90 - Use absolute coordinates
- G91 - Use relative coordinates
- G92 - Set current position to cordinates given

RepRap M Codes

- M104 - Set extruder target temp
- M105 - Read current temp
- M106 - Fan on
- M107 - Fan off
- M109 - Wait for extruder current temp to reach target temp.
- M114 - Display current position

Custom M Codes

- M80  - Turn on Power Supply
- M20  - List SD card
- M21  - Init SD card
- M22  - Release SD card
- M23  - Select SD file (M23 filename.g)
- M24  - Start/resume SD print
- M25  - Pause SD print
- M26  - Set SD position in bytes (M26 S12345)
- M27  - Report SD print status
- M28  - Start SD write (M28 filename.g)
- M29  - Stop SD write
- M30 <filename> - Delete file on sd card
- M32 <dirname> create subdirectory
- M42 P<pin number> S<value 0..255> - Change output of pin P to S. Does not work on most important pins.
- M80  - Turn on power supply
- M81  - Turn off power supply
- M82  - Set E codes absolute (default)
- M83  - Set E codes relative while in Absolute Coordinates (G90) mode
- M84  - Disable steppers until next move,
        or use S<seconds> to specify an inactivity timeout, after which the steppers will be disabled.  S0 to disable the timeout.
- M85  - Set inactivity shutdown timer with parameter S<seconds>. To disable set zero (default)
- M92  - Set axis_steps_per_unit - same syntax as G92
- M112 - Emergency kill
- M115- Capabilities string
- M117 <message> - Write message in status row on lcd
- M119 - Report endstop status
- M140 - Set bed target temp
- M190 - Wait for bed current temp to reach target temp.
- M201 - Set max acceleration in units/s^2 for print moves (M201 X1000 Y1000)
- M202 - Set max acceleration in units/s^2 for travel moves (M202 X1000 Y1000)
- M203 - Set temperture monitor to Sx
- M204 - Set PID parameter X => Kp Y => Ki Z => Kd S<extruder> Default is current extruder. NUM_EXTRUDER=Heated bed
- M205 - Output EEPROM settings
- M206 - Set EEPROM value
- M220 S<Feedrate multiplier in percent> - Increase/decrease given feedrate
- M221 S<Extrusion flow multiplier in percent> - Increase/decrease given flow rate
- M231 S<OPS_MODE> X<Min_Distance> Y<Retract> Z<Backlash> F<ReatrctMove> - Set OPS parameter
- M232 - Read and reset max. advance values
- M233 X<AdvanceK> Y<AdvanceL> - Set temporary advance K-value to X and linear term advanceL to Y
- M251 Measure Z steps from homing stop (Delta printers). S0 - Reset, S1 - Print, S2 - Store to Z length (also EEPROM if enabled)
- M303 P<extruder/bed> S<drucktermeratur> Autodetect pid values. Use P<NUM_EXTRUDER> for heated bed.
- M350 S<mstepsAll> X<mstepsX> Y<mstepsY> Z<mstepsZ> E<mstepsE0> P<mstespE1> : Set microstepping on RAMBO board
- M400 - Wait until move buffers empty.
- M401 - Store x, y and z position.
- M402 - Go to stored position. If X, Y or Z is specified, only these coordinates are used. F changes feedrate fo rthat move.
- M500 Store settings to EEPROM
- M501 Load settings from EEPROM
- M502 Reset settings to the one in configuration.h. Does not store values in EEPROM!
- M908 P<address> S<value> : Set stepper current for digipot (RAMBO board)
*/

#include "Reptier.h"
#include "Eeprom.h"
#include "pins_arduino.h"
#include "fastio.h"
#include "ui.h"
#include <util/delay.h>
#include <SPI.h>

#if UI_DISPLAY_TYPE==4
//#include <LiquidCrystal.h> // Uncomment this if you are using liquid crystal library
#endif

// ================ Sanity checks ================
#ifndef STEP_DOUBLER_FREQUENCY
#error Please add new parameter STEP_DOUBLER_FREQUENCY to your configuration.
#else
#if STEP_DOUBLER_FREQUENCY<10000 || STEP_DOUBLER_FREQUENCY>20000
#error STEP_DOUBLER_FREQUENCY should be in range 10000-16000.
#endif
#endif
#ifdef EXTRUDER_SPEED
#error EXTRUDER_SPEED is not used any more. Values are now taken from extruder definition.
#endif
#if MAX_HALFSTEP_INTERVAL<=1900
#error MAX_HALFSTEP_INTERVAL must be greater then 1900
#endif
#ifdef ENDSTOPPULLUPS
#error ENDSTOPPULLUPS is now replaced by individual pullup configuration!
#endif
#ifdef EXT0_PID_PGAIN
#error The PID system has changed. Please use the new float number options!
#endif
// ####################################################################################
// #          No configuration below this line - just some errorchecking              #
// ####################################################################################
#ifdef SUPPORT_MAX6675
#if !defined SCK_PIN || !defined MOSI_PIN || !defined MISO_PIN
#error For MAX6675 support, you need to define SCK_PIN, MISO_PIN and MOSI_PIN in pins.h
#endif
#endif
#if X_STEP_PIN<0 || Y_STEP_PIN<0 || Z_STEP_PIN<0
#error One of the following pins is not assigned: X_STEP_PIN,Y_STEP_PIN,Z_STEP_PIN
#endif
#if EXT0_STEP_PIN<0 && NUM_EXTRUDER>0
#error EXT0_STEP_PIN not set to a pin number.
#endif
#if EXT0_DIR_PIN<0 && NUM_EXTRUDER>0
#error EXT0_DIR_PIN not set to a pin number.
#endif
#if MOVE_CACHE_SIZE<4
#error MOVE_CACHE_SIZE must be at least 5
#endif

#if DRIVE_SYSTEM==3
#define SIN_60 0.8660254037844386
#define COS_60 0.5
#define DELTA_DIAGONAL_ROD_STEPS (AXIS_STEPS_PER_MM * DELTA_DIAGONAL_ROD)
#define DELTA_DIAGONAL_ROD_STEPS_SQUARED (DELTA_DIAGONAL_ROD_STEPS * DELTA_DIAGONAL_ROD_STEPS)
#define DELTA_ZERO_OFFSET_STEPS (AXIS_STEPS_PER_MM * DELTA_ZERO_OFFSET)
#define DELTA_RADIUS_STEPS (AXIS_STEPS_PER_MM * DELTA_RADIUS)

#define DELTA_TOWER1_X_STEPS -SIN_60*DELTA_RADIUS_STEPS
#define DELTA_TOWER1_Y_STEPS -COS_60*DELTA_RADIUS_STEPS
#define DELTA_TOWER2_X_STEPS SIN_60*DELTA_RADIUS_STEPS
#define DELTA_TOWER2_Y_STEPS -COS_60*DELTA_RADIUS_STEPS
#define DELTA_TOWER3_X_STEPS 0.0
#define DELTA_TOWER3_Y_STEPS DELTA_RADIUS_STEPS

#define NUM_AXIS 4
#define X_AXIS 0
#define Y_AXIS 1
#define Z_AXIS 2
#define E_AXIS 3

#endif

#define OVERFLOW_PERIODICAL  (int)(F_CPU/(TIMER0_PRESCALE*40))
// RAM usage of variables: Non RAMPS 114+MOVE_CACHE_SIZE*59+printer_state(32) = 382 Byte with MOVE_CACHE_SIZE=4
// RAM usage RAMPS adds: 96
// RAM usage SD Card:
byte unit_inches = 0; ///< 0 = Units are mm, 1 = units are inches.
//Stepper Movement Variables
float axis_steps_per_unit[4] = {XAXIS_STEPS_PER_MM,YAXIS_STEPS_PER_MM,ZAXIS_STEPS_PER_MM,1}; ///< Number of steps per mm needed.
float inv_axis_steps_per_unit[4]; ///< Inverse of axis_steps_per_unit for faster conversion
float max_feedrate[4] = {MAX_FEEDRATE_X, MAX_FEEDRATE_Y, MAX_FEEDRATE_Z}; ///< Maximum allowed feedrate.
float homing_feedrate[3] = {HOMING_FEEDRATE_X, HOMING_FEEDRATE_Y, HOMING_FEEDRATE_Z};
byte STEP_PIN[3] = {X_STEP_PIN, Y_STEP_PIN, Z_STEP_PIN};
#ifdef RAMP_ACCELERATION
//  float max_start_speed_units_per_second[4] = MAX_START_SPEED_UNITS_PER_SECOND; ///< Speed we can use, without acceleration.
  long max_acceleration_units_per_sq_second[4] = {MAX_ACCELERATION_UNITS_PER_SQ_SECOND_X,MAX_ACCELERATION_UNITS_PER_SQ_SECOND_Y,MAX_ACCELERATION_UNITS_PER_SQ_SECOND_Z}; ///< X, Y, Z and E max acceleration in mm/s^2 for printing moves or retracts
  long max_travel_acceleration_units_per_sq_second[4] = {MAX_TRAVEL_ACCELERATION_UNITS_PER_SQ_SECOND_X,MAX_TRAVEL_ACCELERATION_UNITS_PER_SQ_SECOND_Y,MAX_TRAVEL_ACCELERATION_UNITS_PER_SQ_SECOND_Z}; ///< X, Y, Z max acceleration in mm/s^2 for travel moves
  /** Acceleration in steps/s^3 in printing mode.*/
  unsigned long axis_steps_per_sqr_second[4];
  /** Acceleration in steps/s^2 in movement mode.*/
  unsigned long axis_travel_steps_per_sqr_second[4];
#endif
#if DRIVE_SYSTEM==3
DeltaSegment segments[DELTA_CACHE_SIZE];
unsigned int delta_segment_write_pos = 0; // Position where we write the next cached delta move
volatile unsigned int  delta_segment_count = 0; // Number of delta moves cached 0 = nothing in cache
byte lastMoveID = 0; // Last move ID
#endif
PrinterState printer_state;
byte relative_mode = false;  ///< Determines absolute (false) or relative Coordinates (true).
byte relative_mode_e = false;  ///< Determines Absolute or Relative E Codes while in Absolute Coordinates mode. E is always relative in Relative Coordinates mode.
byte debug_level = 6; ///< Bitfield defining debug output. 1 = echo, 2 = info, 4 = error, 8 = dry run., 16 = Only communication, 32 = No moves

//Inactivity shutdown variables
unsigned long previous_millis_cmd = 0;
unsigned long max_inactive_time = MAX_INACTIVE_TIME*1000L;
unsigned long stepper_inactive_time = STEPPER_INACTIVE_TIME*1000L;
PrintLine lines[MOVE_CACHE_SIZE]; ///< Cache for print moves.
PrintLine *cur = 0;               ///< Current printing line
byte lines_write_pos=0;           ///< Position where we write the next cached line move.
volatile byte lines_count=0;      ///< Number of lines cached 0 = nothing to do.
byte lines_pos=0;                 ///< Position for executing line movement.
long baudrate = BAUDRATE;         ///< Communication speed rate.
#ifdef USE_ADVANCE
#ifdef ENABLE_QUADRATIC_ADVANCE
int maxadv=0;
#endif
int maxadv2=0;
float maxadvspeed=0;
#endif
byte pwm_pos[NUM_EXTRUDER+3]; // 0-NUM_EXTRUDER = Heater 0-NUM_EXTRUDER of extruder, NUM_EXTRUDER = Heated bed, NUM_EXTRUDER+1 Board fan, NUM_EXTRUDER+2 = Fan

int waitRelax=0; // Delay filament relax at the end of print, could be a simple timeout
#ifdef USE_OPS
byte printmoveSeen=0;
#endif
#ifdef DEBUG_FREE_MEMORY
int lowest_ram=16384;
int lowest_send=16384;

void check_mem() {
BEGIN_INTERRUPT_PROTECTED
  uint8_t * heapptr, * stackptr;
  heapptr = (uint8_t *)malloc(4);          // get heap pointer
  free(heapptr);      // free up the memory again (sets heapptr to 0)
  stackptr =  (uint8_t *)(SP);           // save value of stack pointer
  int newfree = (int)stackptr-(int)heapptr;
  if(newfree<lowest_ram) {
     lowest_ram = newfree;
  }
END_INTERRUPT_PROTECTED
}
void send_mem() {
  if(lowest_send>lowest_ram) {
    lowest_send = lowest_ram;
    out.println_int_P(PSTR("Free RAM:"),lowest_ram);
  }
}
#endif


void update_extruder_flags() {
  printer_state.flag0 &= ~PRINTER_FLAG0_SEPERATE_EXTRUDER_INT;
#if USE_OPS==1
  if(printer_state.opsMode!=0) {
    printer_state.flag0 |= PRINTER_FLAG0_SEPERATE_EXTRUDER_INT;
  }
#endif
#if defined(USE_ADVANCE)
  for(byte i=0;i<NUM_EXTRUDER;i++) {
    if(extruder[i].advanceL!=0) {
      printer_state.flag0 |= PRINTER_FLAG0_SEPERATE_EXTRUDER_INT;
    }
#ifdef ENABLE_QUADRATIC_ADVANCE
    if(extruder[i].advanceK!=0) printer_state.flag0 |= PRINTER_FLAG0_SEPERATE_EXTRUDER_INT;
#endif
  }
#endif
}

void update_ramps_parameter() {
#if DRIVE_SYSTEM==3
  printer_state.zMaxSteps = axis_steps_per_unit[0]*(printer_state.zLength - printer_state.zMin);
  long cart[3], delta[3];
  cart[0] = cart[1] = 0;
  cart[2] = printer_state.zMaxSteps;
  calculate_delta(cart, delta);
  printer_state.maxDeltaPositionSteps = delta[0];
  printer_state.xMaxSteps = (long)(axis_steps_per_unit[0]*(printer_state.xMin+printer_state.xLength));
  printer_state.yMaxSteps = (long)(axis_steps_per_unit[1]*(printer_state.yMin+printer_state.yLength));
  printer_state.xMinSteps = (long)(axis_steps_per_unit[0]*printer_state.xMin);
  printer_state.yMinSteps = (long)(axis_steps_per_unit[1]*printer_state.yMin);
  printer_state.zMinSteps = 0;
#else
  printer_state.xMaxSteps = (long)(axis_steps_per_unit[0]*(printer_state.xMin+printer_state.xLength));
  printer_state.yMaxSteps = (long)(axis_steps_per_unit[1]*(printer_state.yMin+printer_state.yLength));
  printer_state.zMaxSteps = (long)(axis_steps_per_unit[2]*(printer_state.zMin+printer_state.zLength));
  printer_state.xMinSteps = (long)(axis_steps_per_unit[0]*printer_state.xMin);
  printer_state.yMinSteps = (long)(axis_steps_per_unit[1]*printer_state.yMin);
  printer_state.zMinSteps = (long)(axis_steps_per_unit[2]*printer_state.zMin);
  // For which directions do we need backlash compensation
#if ENABLE_BACKLASH_COMPENSATION
  printer_state.backlashDir &= 7;
  if(printer_state.backlashX!=0) printer_state.backlashDir |= 8;
  if(printer_state.backlashY!=0) printer_state.backlashDir |= 16;
  if(printer_state.backlashZ!=0) printer_state.backlashDir |= 32;
  /*if(printer_state.backlashDir & 56)
    OUT_P_LN("Backlash compensation enabled");
  else
    OUT_P_LN("Backlash compensation disabled");*/
#endif
#endif
  for(byte i=0;i<4;i++) {
    inv_axis_steps_per_unit[i] = 1.0f/axis_steps_per_unit[i];
#ifdef RAMP_ACCELERATION
    /** Acceleration in steps/s^3 in printing mode.*/
    axis_steps_per_sqr_second[i] = max_acceleration_units_per_sq_second[i] * axis_steps_per_unit[i];
    /** Acceleration in steps/s^2 in movement mode.*/
    axis_travel_steps_per_sqr_second[i] = max_travel_acceleration_units_per_sq_second[i] * axis_steps_per_unit[i];
#endif
  }
  float accel = max(max_acceleration_units_per_sq_second[0],max_travel_acceleration_units_per_sq_second[0]);
  printer_state.minimumSpeed = accel*sqrt(2.0f/(axis_steps_per_unit[0]*accel));
  update_extruder_flags();
}

/** \brief Setup of the hardware

Sets the output and input pins in accordance to your configuration. Initializes the serial interface.
Interrupt routines to measure analog values and for the stepper timerloop are started.
*/
void setup()
{
#ifdef ANALYZER
// Channel->pin assignments
#if ANALYZER_CH0>=0
SET_OUTPUT(ANALYZER_CH0);
#endif
#if ANALYZER_CH1>=0
SET_OUTPUT(ANALYZER_CH1);
#endif
#if ANALYZER_CH2>=0
SET_OUTPUT(ANALYZER_CH2);
#endif
#if ANALYZER_CH3>=0
SET_OUTPUT(ANALYZER_CH3);
#endif
#if ANALYZER_CH4>=0
SET_OUTPUT(ANALYZER_CH4);
#endif
#if ANALYZER_CH5>=0
SET_OUTPUT(ANALYZER_CH5);
#endif
#if ANALYZER_CH6>=0
SET_OUTPUT(ANALYZER_CH6);
#endif
#if ANALYZER_CH7>=0
SET_OUTPUT(ANALYZER_CH7);
#endif
#endif
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
void loop()
{
  gcode_read_serial();
  GCode *code = gcode_next_command();
  //UI_SLOW; // do longer timed user interface action
  UI_MEDIUM; // do check encoder
  if(code){
#if SDSUPPORT
    if(sd.savetosd){
        if(!(GCODE_HAS_M(code) && code->M==29)) { // still writing to file
            sd.write_command(code);
        } else {
            sd.finishWrite();
        }
#ifdef ECHO_ON_EXECUTE
        if(DEBUG_ECHO) {
           OUT_P("Echo:");
           gcode_print_command(code);
           out.println();
        }
#endif
        gcode_command_finished(code);
    } else {
        process_command(code,true);
    }
#else
    process_command(code,true);
#endif
  }
  defaultLoopActions();
}


/** \brief Optimized division

Normally the C compiler will compute a long/long division, which takes ~670 Ticks.
This version is optimized for a 16 bit dividend and recognises the special cases
of a 24 bit and 16 bit dividend, which offen, but not always occur in updating the
interval.
*/
inline long Div4U2U(unsigned long a,unsigned int b) {
#if CPU_ARCH==ARCH_AVR
  // r14/r15 remainder
  // r16 counter
  __asm__ __volatile__ (
  "clr r14 \n\t"
  "sub r15,r15 \n\t"
  "tst %D0 \n\t"
  "brne do32%= \n\t"
  "tst %C0 \n\t"
  "breq donot24%= \n\t"
  "rjmp do24%= \n\t"
  "donot24%=:" "ldi r16,17 \n\t" // 16 Bit divide
  "d16u_1%=:" "rol %A0 \n\t"
  "rol %B0 \n\t"
  "dec r16 \n\t"
  "brne	d16u_2%= \n\t"
  "rjmp end%= \n\t"
  "d16u_2%=:" "rol r14 \n\t"
  "rol r15 \n\t"
  "sub r14,%A2 \n\t"
  "sbc r15,%B2 \n\t"
  "brcc	d16u_3%= \n\t"
  "add r14,%A2 \n\t"
  "adc r15,%B2 \n\t"
  "clc \n\t"
  "rjmp d16u_1%= \n\t"
  "d16u_3%=:" "sec \n\t"
  "rjmp d16u_1%= \n\t"
  "do32%=:" // divide full 32 bit
  "rjmp do32B%= \n\t"
  "do24%=:" // divide 24 bit

  "ldi r16,25 \n\t" // 24 Bit divide
  "d24u_1%=:" "rol %A0 \n\t"
  "rol %B0 \n\t"
  "rol %C0 \n\t"
  "dec r16 \n\t"
  "brne	d24u_2%= \n\t"
  "rjmp end%= \n\t"
  "d24u_2%=:" "rol r14 \n\t"
  "rol r15 \n\t"
  "sub r14,%A2 \n\t"
  "sbc r15,%B2 \n\t"
  "brcc	d24u_3%= \n\t"
  "add r14,%A2 \n\t"
  "adc r15,%B2 \n\t"
  "clc \n\t"
  "rjmp d24u_1%= \n\t"
  "d24u_3%=:" "sec \n\t"
  "rjmp d24u_1%= \n\t"

  "do32B%=:" // divide full 32 bit

  "ldi r16,33 \n\t" // 32 Bit divide
  "d32u_1%=:" "rol %A0 \n\t"
  "rol %B0 \n\t"
  "rol %C0 \n\t"
  "rol %D0 \n\t"
  "dec r16 \n\t"
  "brne	d32u_2%= \n\t"
  "rjmp end%= \n\t"
  "d32u_2%=:" "rol r14 \n\t"
  "rol r15 \n\t"
  "sub r14,%A2 \n\t"
  "sbc r15,%B2 \n\t"
  "brcc	d32u_3%= \n\t"
  "add r14,%A2 \n\t"
  "adc r15,%B2 \n\t"
  "clc \n\t"
  "rjmp d32u_1%= \n\t"
  "d32u_3%=:" "sec \n\t"
  "rjmp d32u_1%= \n\t"

  "end%=:" // end
  :"=&r"(a)
  :"0"(a),"r"(b)
  :"r14","r15","r16"
  );
 return a;
#else
  return a/b;
#endif
}

const uint16_t fast_div_lut[17] PROGMEM = {0,F_CPU/4096,F_CPU/8192,F_CPU/12288,F_CPU/16384,F_CPU/20480,F_CPU/24576,F_CPU/28672,F_CPU/32768,F_CPU/36864
  ,F_CPU/40960,F_CPU/45056,F_CPU/49152,F_CPU/53248,F_CPU/57344,F_CPU/61440,F_CPU/65536};

const uint16_t slow_div_lut[257] PROGMEM = {0,F_CPU/32,F_CPU/64,F_CPU/96,F_CPU/128,F_CPU/160,F_CPU/192,F_CPU/224,F_CPU/256,F_CPU/288,F_CPU/320,F_CPU/352
 ,F_CPU/384,F_CPU/416,F_CPU/448,F_CPU/480,F_CPU/512,F_CPU/544,F_CPU/576,F_CPU/608,F_CPU/640,F_CPU/672,F_CPU/704,F_CPU/736,F_CPU/768,F_CPU/800,F_CPU/832
 ,F_CPU/864,F_CPU/896,F_CPU/928,F_CPU/960,F_CPU/992,F_CPU/1024,F_CPU/1056,F_CPU/1088,F_CPU/1120,F_CPU/1152,F_CPU/1184,F_CPU/1216,F_CPU/1248,F_CPU/1280,F_CPU/1312
 ,F_CPU/1344,F_CPU/1376,F_CPU/1408,F_CPU/1440,F_CPU/1472,F_CPU/1504,F_CPU/1536,F_CPU/1568,F_CPU/1600,F_CPU/1632,F_CPU/1664,F_CPU/1696,F_CPU/1728,F_CPU/1760,F_CPU/1792
 ,F_CPU/1824,F_CPU/1856,F_CPU/1888,F_CPU/1920,F_CPU/1952,F_CPU/1984,F_CPU/2016
 ,F_CPU/2048,F_CPU/2080,F_CPU/2112,F_CPU/2144,F_CPU/2176,F_CPU/2208,F_CPU/2240,F_CPU/2272,F_CPU/2304,F_CPU/2336,F_CPU/2368,F_CPU/2400
 ,F_CPU/2432,F_CPU/2464,F_CPU/2496,F_CPU/2528,F_CPU/2560,F_CPU/2592,F_CPU/2624,F_CPU/2656,F_CPU/2688,F_CPU/2720,F_CPU/2752,F_CPU/2784,F_CPU/2816,F_CPU/2848,F_CPU/2880
 ,F_CPU/2912,F_CPU/2944,F_CPU/2976,F_CPU/3008,F_CPU/3040,F_CPU/3072,F_CPU/3104,F_CPU/3136,F_CPU/3168,F_CPU/3200,F_CPU/3232,F_CPU/3264,F_CPU/3296,F_CPU/3328,F_CPU/3360
 ,F_CPU/3392,F_CPU/3424,F_CPU/3456,F_CPU/3488,F_CPU/3520,F_CPU/3552,F_CPU/3584,F_CPU/3616,F_CPU/3648,F_CPU/3680,F_CPU/3712,F_CPU/3744,F_CPU/3776,F_CPU/3808,F_CPU/3840
 ,F_CPU/3872,F_CPU/3904,F_CPU/3936,F_CPU/3968,F_CPU/4000,F_CPU/4032,F_CPU/4064
 ,F_CPU/4096,F_CPU/4128,F_CPU/4160,F_CPU/4192,F_CPU/4224,F_CPU/4256,F_CPU/4288,F_CPU/4320,F_CPU/4352,F_CPU/4384,F_CPU/4416,F_CPU/4448,F_CPU/4480,F_CPU/4512,F_CPU/4544
 ,F_CPU/4576,F_CPU/4608,F_CPU/4640,F_CPU/4672,F_CPU/4704,F_CPU/4736,F_CPU/4768,F_CPU/4800,F_CPU/4832,F_CPU/4864,F_CPU/4896,F_CPU/4928,F_CPU/4960,F_CPU/4992,F_CPU/5024
 ,F_CPU/5056,F_CPU/5088,F_CPU/5120,F_CPU/5152,F_CPU/5184,F_CPU/5216,F_CPU/5248,F_CPU/5280,F_CPU/5312,F_CPU/5344,F_CPU/5376,F_CPU/5408,F_CPU/5440,F_CPU/5472,F_CPU/5504
 ,F_CPU/5536,F_CPU/5568,F_CPU/5600,F_CPU/5632,F_CPU/5664,F_CPU/5696,F_CPU/5728,F_CPU/5760,F_CPU/5792,F_CPU/5824,F_CPU/5856,F_CPU/5888,F_CPU/5920,F_CPU/5952,F_CPU/5984
 ,F_CPU/6016,F_CPU/6048,F_CPU/6080,F_CPU/6112,F_CPU/6144,F_CPU/6176,F_CPU/6208,F_CPU/6240,F_CPU/6272,F_CPU/6304,F_CPU/6336,F_CPU/6368,F_CPU/6400,F_CPU/6432,F_CPU/6464
 ,F_CPU/6496,F_CPU/6528,F_CPU/6560,F_CPU/6592,F_CPU/6624,F_CPU/6656,F_CPU/6688,F_CPU/6720,F_CPU/6752,F_CPU/6784,F_CPU/6816,F_CPU/6848,F_CPU/6880,F_CPU/6912,F_CPU/6944
 ,F_CPU/6976,F_CPU/7008,F_CPU/7040,F_CPU/7072,F_CPU/7104,F_CPU/7136,F_CPU/7168,F_CPU/7200,F_CPU/7232,F_CPU/7264,F_CPU/7296,F_CPU/7328,F_CPU/7360,F_CPU/7392,F_CPU/7424
 ,F_CPU/7456,F_CPU/7488,F_CPU/7520,F_CPU/7552,F_CPU/7584,F_CPU/7616,F_CPU/7648,F_CPU/7680,F_CPU/7712,F_CPU/7744,F_CPU/7776,F_CPU/7808,F_CPU/7840,F_CPU/7872,F_CPU/7904
 ,F_CPU/7936,F_CPU/7968,F_CPU/8000,F_CPU/8032,F_CPU/8064,F_CPU/8096,F_CPU/8128,F_CPU/8160,F_CPU/8192
 };
/** \brief approximates division of F_CPU/divisor

In the stepper interrupt a division is needed, which is a slow operation.
The result is used for timer calculation where small errors are ok. This
function uses lookup tables to find a fast approximation of the result.
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

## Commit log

2013-08-20 Initial Upload
    Initial Upload, with Heated Bed files
    [58744_REV1_BoardOutline.gbr, 58744_REV1_Bottom.gbr, 58744_REV1_BottomMask.gbr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]
2013-09-15 Uploading initial firmware
    Adding firmware folder. This firmware is based on repetier 0.83
    firmware, but works with RAMBo board and our delta pinout
    [Configuration.h]
2013-09-25 UPDATING FIRMWARE
    updating firmware for ORION. New tested accel/jerk settings all around,
    as verified on first 5 production machines
    [Configuration.h]
2013-09-26 adjusted configuration.h
    Adjusted configuration.h to match machines as shipping
    [Configuration.h]
2013-10-02 Added CAD Files
    Added eAssembly files and Laser Cut files for the ORION Delta Printer
2013-10-02 ORION IGES CAD files added
    PartDaddy added IGES CAD files for the ORION
    [17505 LEG.IGS, 40mmFAN.IGS, 44010 FOOT.IGS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]
2013-10-07 updated quickstart content
    added source code for quick start content powered by reveal.js
2013-10-15 Added SDCARD files
    These are the files included on the SD card when the ORION ships. It
    contains firmware used on each machine, test print gcode, and
    calibration routines
    [Configuration.h, TcfTransactionLog.csv]
2013-11-21 Included old style extruder mount files
    Added the old prototype top mount extruder files for anyone who wanted
    to modify their machine to that style
    [70769 Spacer.DXF, 70770 EZStruder Support qty1.DXF, 70771 EZSpool Part A.DXF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]
2013-11-25 Removed M106's form gcode files for abs
    Removed M106 so ABS prints without part fans on
2013-11-28 Added temperature curve section
2013-12-09 CHANGED cooler_pin to be constant on
    Updataed repetier.ino to turn ON pin 7 ALWAYS and changed
    configuration.h to set cooler fan to -1 so there's no conflicts.
    MAKE SURE if you are trying to use dual extruders you do not use HEAT_1
    as the extruder, or remove the code here to allow it to be back to
    switchable
    [Configuration.h]
2013-12-19 fixed bed kill command
    added bed kill code to ui.cpp
    [Repetier.ino, ui.cpp]
2013-12-19 fixed calibrations
    fixed cals
2013-12-19 updated kill button code
    fixed kill button to shut heats off and home machine
    [Repetier.ino, ui.cpp]
2014-01-31 Created 2nd edition to cover the new .91 firmware release!
    [Part1.sldprt]
2014-02-06 removed firmware folder from SD card
    [Configuration.h, TcfTransactionLog.csv]
2014-02-06 renamed firmware folder
    renamed fw folder to the old original 083
    [Configuration.h]
2014-02-12 Added comments to both editions to point out the change point for the firmware update on shipping printers.
2014-02-19 Updated CAD Files
    ADDED BLINKY TRUCKS
    UPDATED HB INSULATOR FOR NEW HEATED BED DESIGN
    UPDATED SPOOL HOLDERS FOR LONG SPOOLS
    REMOVED SOME NON-USED HOLES
    UPDATED EXTRUDER PANEL TO MAKE REPLACEMENT EASIER
    UPDATED LCD SIDES FOR MORE NUT CLEARANCE
    UPDATED HOTEND MOUNT FOR BETTER WIRE MANAGEMENT
    [ACRYLIC_FACEPLATE_FLEXY_V3.DXF, ACRYLIC_IDLER_COVERS.DXF, ACRYLIC_SQUARES_114MM.DXF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]
2014-03-23 Added calibration process.
2014-06-20 updated Heated Bed files
    updated Heated bed files to newest versions
    [58744_REV1_BoardOutline.gbr, 58744_REV1_Bottom.gbr, 58744_REV1_BottomMask.gbr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]
2014-08-27 Updates to match current shipping version.
2015-02-25 Added print example image

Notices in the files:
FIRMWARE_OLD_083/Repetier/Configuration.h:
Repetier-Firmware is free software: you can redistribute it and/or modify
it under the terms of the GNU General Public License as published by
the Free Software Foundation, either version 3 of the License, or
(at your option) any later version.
